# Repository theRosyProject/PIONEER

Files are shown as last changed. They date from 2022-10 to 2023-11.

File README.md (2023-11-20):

# PIONEER
Marie Skłodowska-Curie grant agreement No. 844526 

https://cordis.europa.eu/project/id/844526

## Publications
Dallo, Federico, et al. "Calibration and assessment of electrochemical low-cost sensors in remote alpine harsh environments." Atmospheric Measurement Techniques 14.9 (2021): 6005-6021. https://doi.org/10.5194/amt-14-6005-2021

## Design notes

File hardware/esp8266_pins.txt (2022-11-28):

# Connections with the LoRa Module
3V -- 3V
GND -- GND
14/SCK -- SCK
13/MOSI -- MOSI
12/MISO -- MISO
15 -- G0
16 -- RST
2 -- CS

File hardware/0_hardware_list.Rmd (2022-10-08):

---
title: "Harware List"
author: 
  - "Federico Dallo"
  - "Naichen Zhao"
date: "2022-09-19"
output: html_document
---

```{r setup, include=FALSE}
knitr::opts_chunk$set(echo = TRUE)
```

# List of modules

## Box 1: Data Communication 

The data communication box will receive data (UART) from `Box 2: Data Collection` and will be powered (9V - 5V) with the `Box 3: Power Supply`.

The PCB have to be design to act both as `receiver` and `transceiver` and capable to plug-in commercial components:

- Raspberry Pi Zero ([3B+](https://www.raspberrypi.com/products/raspberry-pi-3-model-b-plus/), [Zero](https://www.raspberrypi.com/products/raspberry-pi-zero-2-w/)) 
- Arduino [Nano BLE](https://store-usa.arduino.cc/products/arduino-nano-33-ble?selectedStore=us)
- [ESP32-S3-MINI-1](https://www.adafruit.com/product/5477)
   - [documentation](https://docs.espressif.com/projects/arduino-esp32/en/latest/installing.html)
- [Feather Huzzah ESP8266](https://www.adafruit.com/product/2821)

Additional modules that should be integrated in the PCB:

- [LoRa 868MHz](https://www.adafruit.com/product/3072)
  - [alternative](https://www.digikey.com/en/products/detail/seeed-technology-co.,-ltd/109990166/7033232?utm_adgroup=RF%20Transceiver%20Modules&utm_source=google&utm_medium=cpc&utm_campaign=Shopping_Product_RF%2FIF%20and%20RFID_NEW&utm_term=&utm_content=RF%20Transceiver%20Modules&gclid=CjwKCAjwpqCZBhAbEiwAa7pXeRL7nhQhQ7vTGvsG-45Smy6gd5Uc4cDUkz6kC4OnWObWKTFqP0Ql0xoCmRAQAvD_BwE)
- Temperature/Humidity/Pressure [BME280](https://www.adafruit.com/product/2652)
- [RTC](https://www.adafruit.com/product/3013)

The connectors that should be on the board:

- Power (USB-C) *Note: the connection should be protected inside the box, with a kind of internal "winding" of the wire to prevent detachment from the board
- [SMA (example)](https://www.adafruit.com/product/1865) 
- [3-pins power connector](https://www.amazon.com/CNLINKO-Industrial-Connector-Receptacles-Waterproof/dp/B06XFM835T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)
- [4-pins data communication connector](https://www.amazon.com/CNLINKO-Industrial-Connector-Receptacles-Waterproof/dp/B06XFMQHWM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)

Notes:

- 868 MHz antenna
  - (Taoglass)[https://www.taoglas.com/product/barracuda-omb-868-05f21-868mhz-omni-directional-outdoor-antenna/]

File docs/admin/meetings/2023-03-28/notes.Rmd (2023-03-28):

---
title: "2023-03-28"
author: "Federico Dallo"
date: "`r Sys.Date()`"
output: html_document
---

```{r setup, include=FALSE}
knitr::opts_chunk$set(echo = TRUE)
```

## Note

- (High) How much time for assembling sensing systems and gateways? 
  - Cost per unit? Prepare: 20 PAT, 100 RICK
- (Medium) Design CAD of the RICK sensors' holes

## PCB updates

- (Low) Add a LoRa 868 MHz antenna on the PAT PCB, on the corner (https://www.proto-electronics.com/blog/how-to-design-pcb-antennas)
- (Medium) Add RTC to the RICK PCB (below?, on the same i2c connections used for the x49 ADC? Loosing CO2, which is ok as CO2 is more important in homes where there is wifi and there is no need of RTC and SD CARD)
- (High - Documentation) Add minimum instruction/labels on the sensors' PCB to ease the installation of modules.
  - ADC mounting orientation and i2c address (RTC orientation as well for the x49 ADC)
  - 4 pin for the CO2 sensor should have V-G-N-P labels
  - 4 pin TX-RX-GND-V on the power and serial
  
## Next Project: Indoor Environment

- EPS8266 controller
- junction box (https://www.thespruce.com/electrical-switch-and-junction-boxes-1824666)
- cover plate: holes for the sensors, button for configuration & reset, led for debug. (If possible an USB Type A for interfacing with the esp, but also for recharging a phone?)
- if not possible having an USB Type A socket, provide a USB socket easy to access when removing the plate, for eventual direct access to the microcontroller

## Other

- (Low) Add an IP56 USB socket on the box

## Aknowledgement

PIONEER ... module
F. Dallo & N. Zhao

## Citation

### Place the original in Spanish
Defender la alegría como una trinchera,
un principio, una bandera, un destino,
una certeza, un derecho. (M. Benedetti)

Difendere l’allegria come una trincea, 
un principio, una bandiera, un destino, 
una certezza, un diritto. (M. Benedetti)

http://tiltingourheadsup.blogspot.com/2012/11/mario-benedetti-in-defence-of-joy.html

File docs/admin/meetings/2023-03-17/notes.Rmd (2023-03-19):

---
title: "Notes"
author: "Federico Dallo"
date: "`r Sys.Date()`"
output: html_document
---

```{r setup, include=FALSE}
knitr::opts_chunk$set(echo = TRUE)
```

## Updates to be made on Sensor PCB

Add minimum instruction/labels on the sensors' PCB to ease the installation of modules.
For example: 

- ADC mounting orientation and i2c address
- 4 pin for the CO2 sensor should have V-G-N-P labels
- 4 pin TX-RX-GND-V on the power and serial

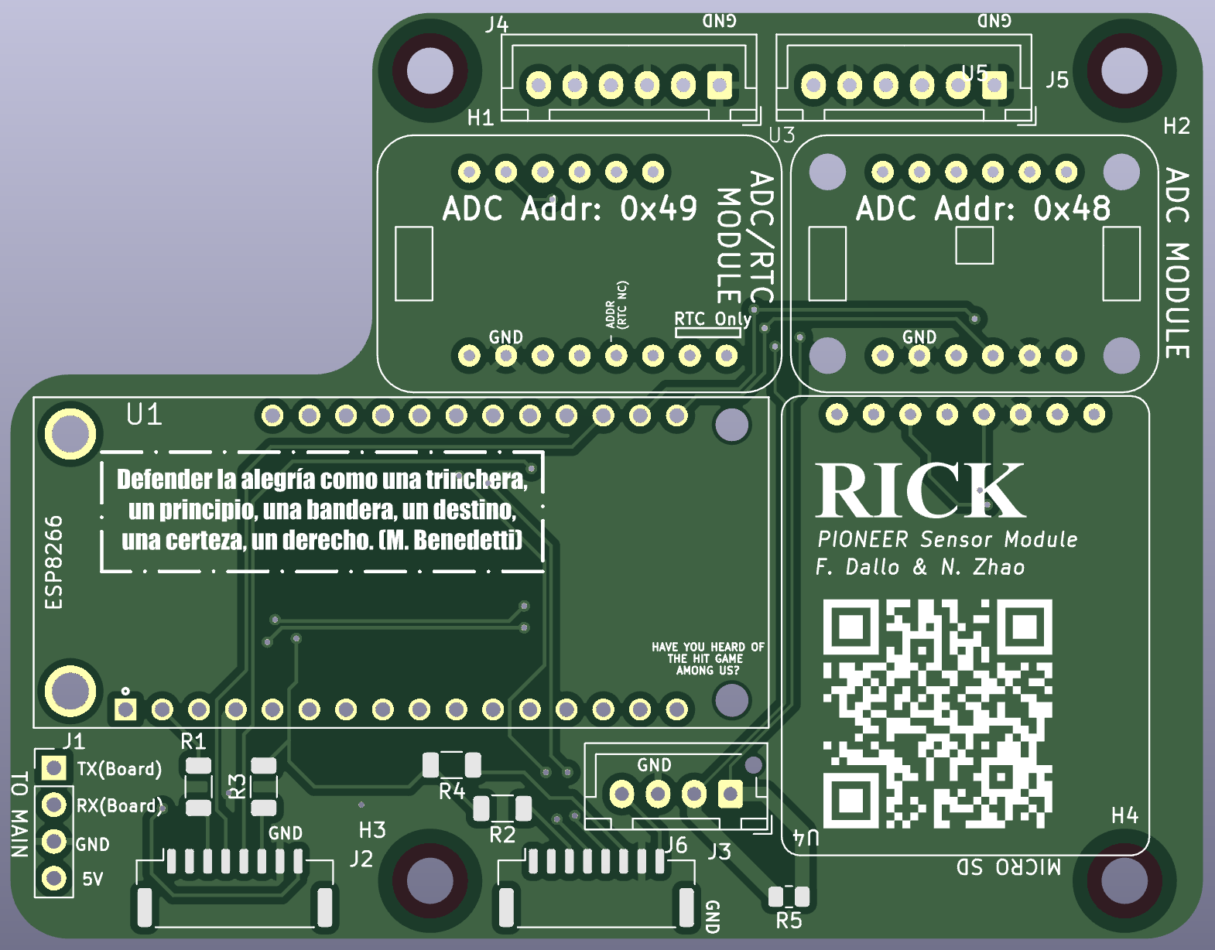
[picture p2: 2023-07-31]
hardware/RICK_v1.png

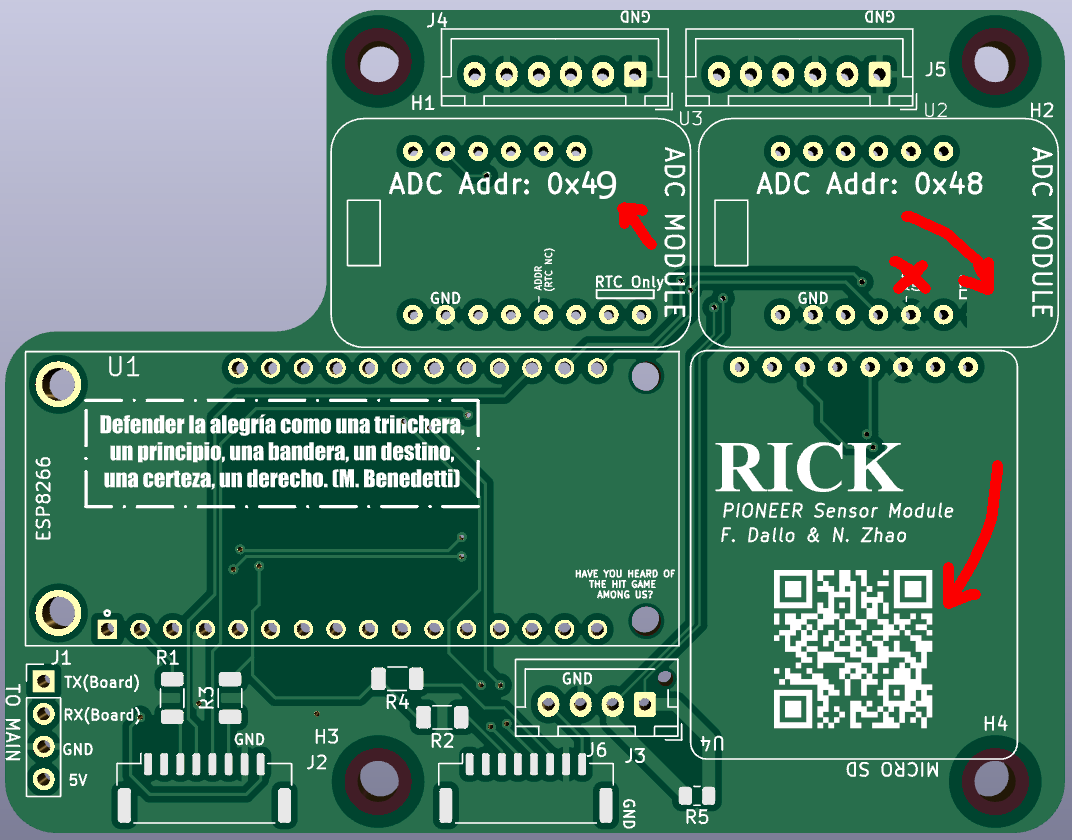
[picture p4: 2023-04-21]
docs/admin/meetings/2023-04-20/RICK.png

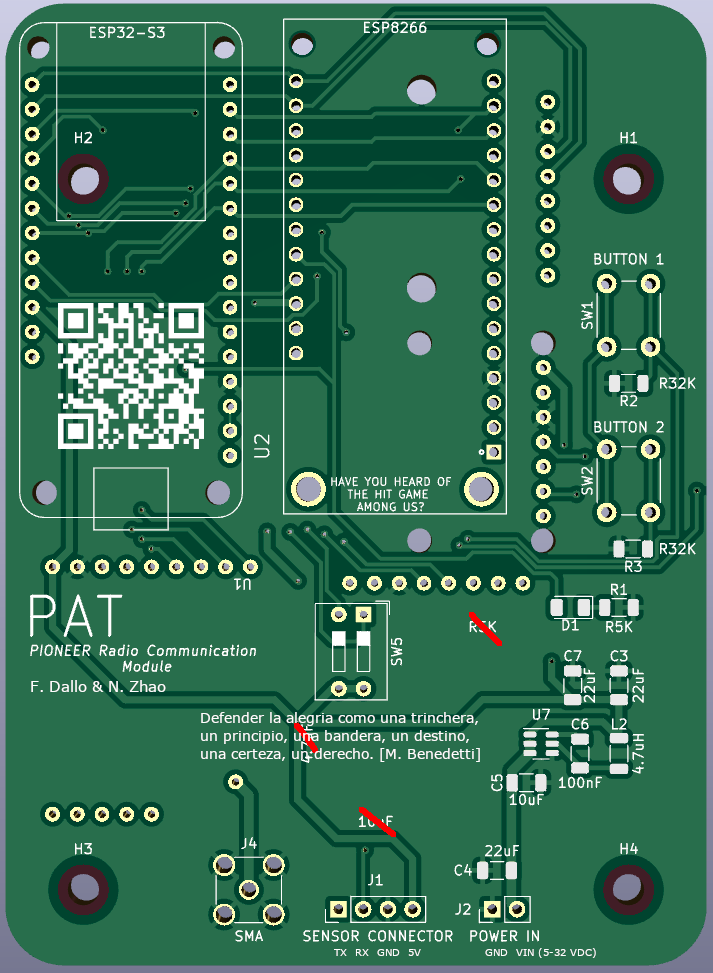
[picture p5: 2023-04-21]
docs/admin/meetings/2023-04-20/PAT.png

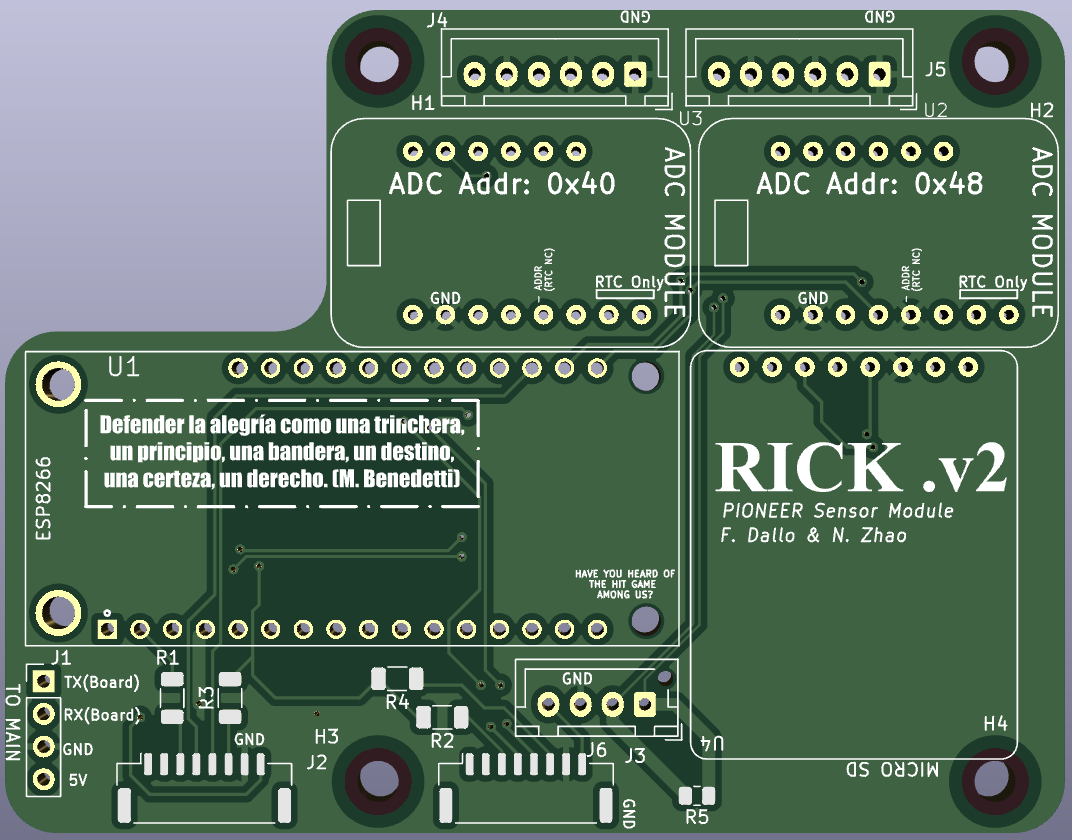
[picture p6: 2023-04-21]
docs/admin/meetings/2023-04-20/Screenshot 2023-04-20 at 15.49.45.png

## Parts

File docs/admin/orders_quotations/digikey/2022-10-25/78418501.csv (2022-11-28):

# | QUANTITY | PART NUMBER | MANUFACTURER PART NUMBER | DESCRIPTION | CUSTOMER REFERENCE | BACKORDER | UNIT PRICE | EXTENDED PRICE
1 | 50 | 399-C1206C472K5RACAUTOCT-ND | C1206C472K5RACAUTO | CAP CER 4700PF 50V X7R 1206 |  | 0 | 0.07500 | 3.75
2 | 20 | 399-17654-1-ND | C1206C103JBGAC7800 | CAP CER SMD 1206 .01UF 630V 5% C |  | 0 | 0.72400 | 14.48
3 | 50 | 445-5840-1-ND | CGA5L2X7R2A104K160AA | CAP CER 0.1UF 100V X7R 1206 |  | 0 | 0.13340 | 6.67
4 | 20 | 478-12850-1-ND | 1206CC223KAT1A | CAP CER 0.022UF 630V X7R 1206 |  | 0 | 0.53000 | 10.60
5 | 20 | 160-1737-1-ND | LTW-150TK | LED WHITE CHIP SMD |  | 0 | 0.36900 | 7.38
6 | 25 | 283-MCQ1V3216-2R2-RCT-ND | MCQ1V3216-2R2-R | FIXED IND 2.2UH 50MA 500MOHM SMD |  | 0 | 0.06480 | 1.62
7 | 20 | 4161-CTML1206F-4R7K-ND | CTML1206F-4R7K | 4.7UH FER MULTIL SHLD INDUCTOR |  | 0 | 0.22000 | 4.40
8 | 25 | 2223-DS01-254-L-02BE-ND | DS01-254-L-02BE | DIP SWITCH, SPST, 2.54 PITCH, RA |  | 0 | 0.46480 | 11.62
9 | 10 | LM3671MF-3.3/NOPBCT-ND | LM3671MF-3.3/NOPB | IC REG BUCK 3.3V 600MA SOT23-5 |  | 0 | 1.56500 | 15.65
10 | 10 | AP63205WU-7DICT-ND | AP63205WU-7 | IC REG BUCK 5V 2A TSOT26 |  | 0 | 0.79900 | 7.99

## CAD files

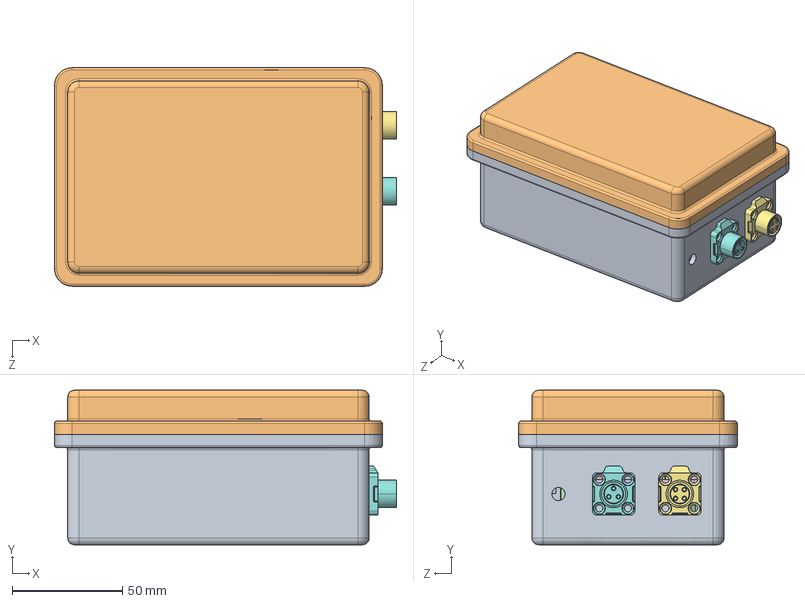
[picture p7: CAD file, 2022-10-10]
hardware/CAD/Box_Assembly.SLDASM
154.9 x 70.0 x 99.0 mm
PCB_Holder
15mm Standoff x 4
CONSMA001-ND
Tactal Switch -Thru (6mmx 6mmx4.5mm) x 4
SW-NDS-02V.stp
12er Pin Header Female.step x 2
16er Pin Header Female.step x 2
8er Pin Header Female.step
7er Pin Header Female.step
5er Pin Header Female.step
9er Pin Header Female.step
Pioneer Controller
Connector Cnlinko LP-12 4 poles
Connector Cnlinko LP-12 3 poles

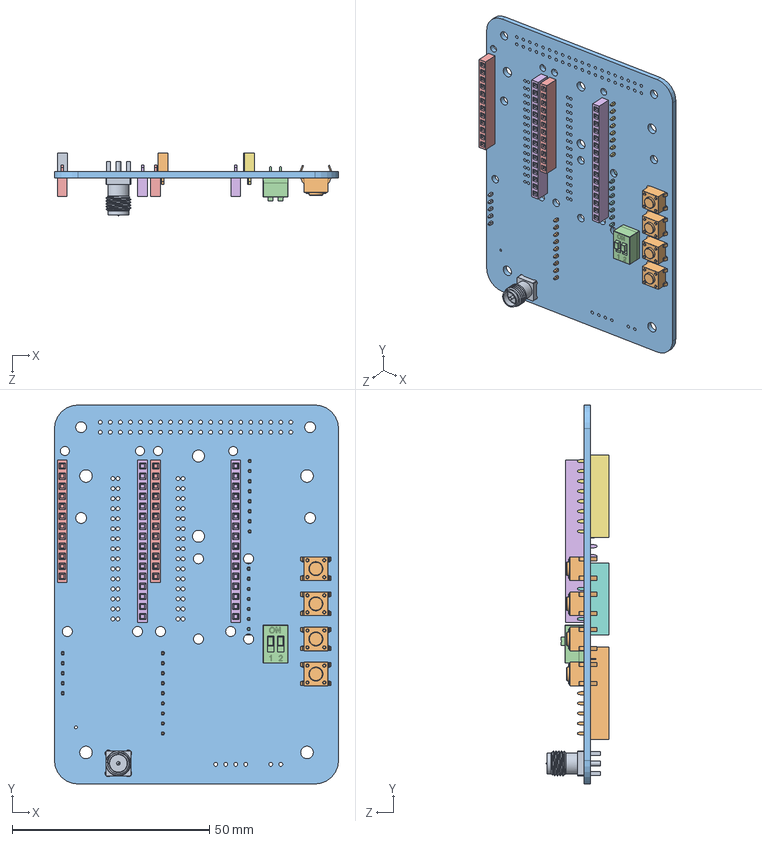
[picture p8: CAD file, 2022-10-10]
hardware/CAD/PCB Models/PCB_Assembly.SLDASM
72.0 x 96.0 x 16.0 mm
CONSMA001-ND
Tactal Switch -Thru (6mmx 6mmx4.5mm) x 4
PCB_Board
SW-NDS-02V.stp
12er Pin Header Female.step x 2
16er Pin Header Female.step x 2
8er Pin Header Female.step
7er Pin Header Female.step
5er Pin Header Female.step
9er Pin Header Female.step

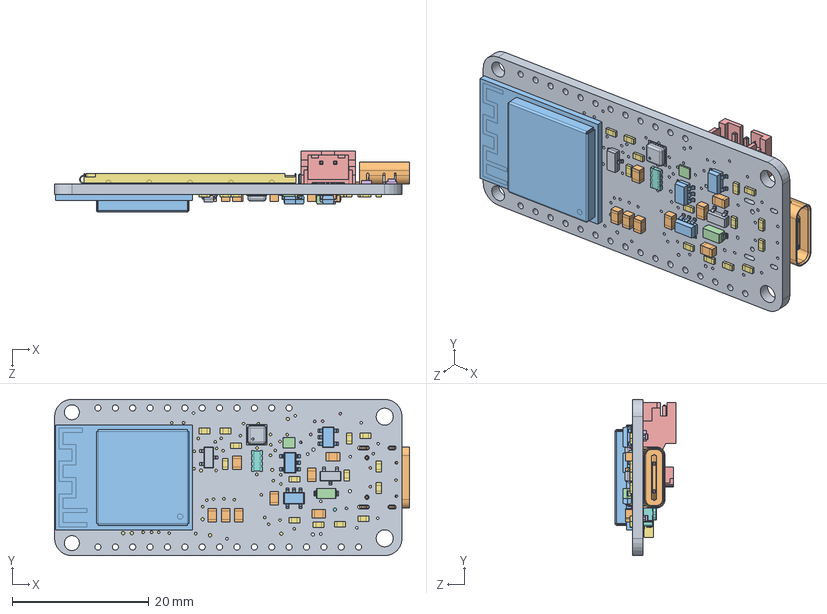
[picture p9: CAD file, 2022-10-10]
hardware/Controller Box/PCB Models/Controllers/ESP32-S2/5300 ESP32-S2 TFT Feather.SLDASM
51.9 x 22.9 x 8.92 mm
Board.step
10uF.step x 8
AP2112-3.3.step x 3
MBR540.step
JSTPH.step
RED.step x 2
1uF.step x 14
KMR2.step x 2
BSS138.step x 2
USB C.step
ESP32-S2-MODULE_MINI.step
LC709203F_MH.step
STEMMA_I2C_QTRA.step
WS2812B_SK6805_1515.step
DISP_LCD_GENERIC_SPI_1.14IN_240X135_WRAPUNDER.step
10K.step
BME680.step

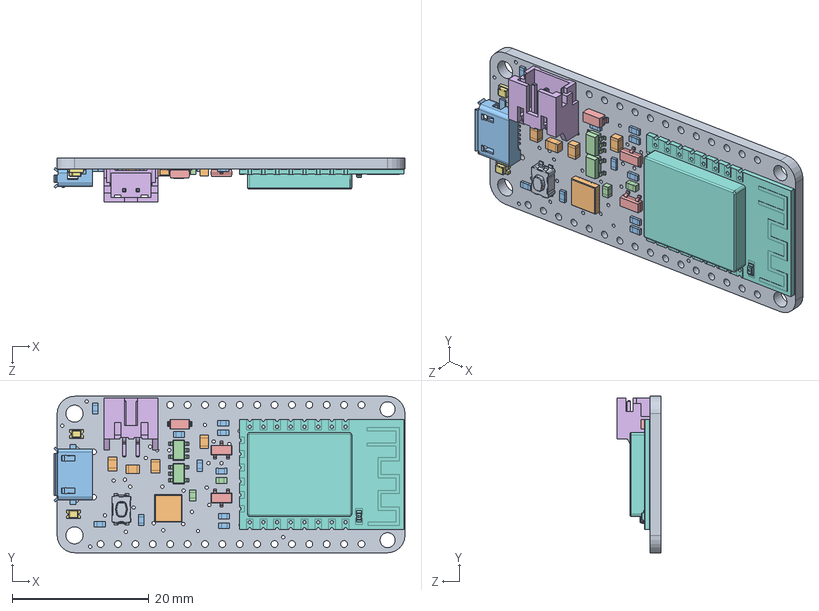
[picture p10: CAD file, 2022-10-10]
hardware/Controller Box/PCB Models/Controllers/ESP8266/Adafruit ESP8266 Feather.SLDASM
51.3 x 22.9 x 6.37 mm
Board.step
10uF.step x 4
10K.step x 10
MCP73831T-2ACI_OT.step x 2
MBR120.step
JSTPH.step
RED.step x 2
ESP-12.step
KMR2.step
CP2104.step
20329.step
1K.step x 2
mmbt2222.step x 2

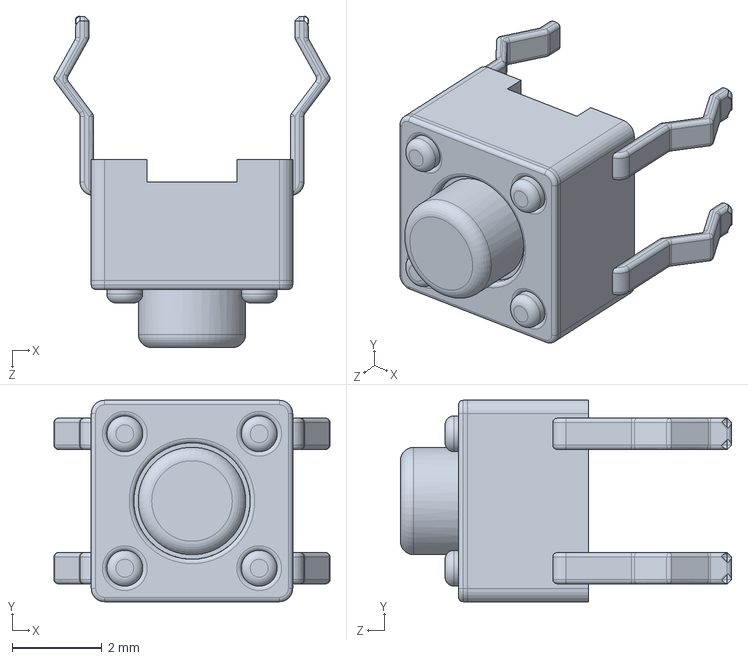
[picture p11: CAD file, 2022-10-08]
hardware/Controller Box/PCB Models/Tact Switch 4.5mm.SLDASM
6.16 x 4.50 x 7.40 mm

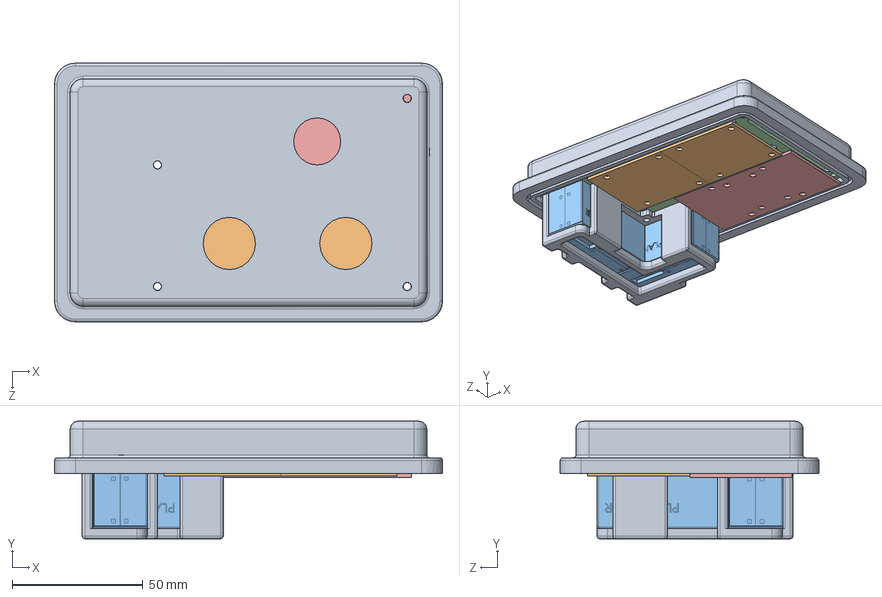
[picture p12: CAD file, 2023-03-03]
hardware/Sensor Box/Sensor_Box_Top_Ass.SLDASM
148.5 x 45.0 x 99.0 mm
Sensor_Box_Lid
Alphsense_Gas_Sensor x 2
PMS5003 x 2
top_frame
NDIR Transmitter
10mm Standoff x 4
3mm Standoff x 4
2.5mm Standoff x 8
PM5_frame

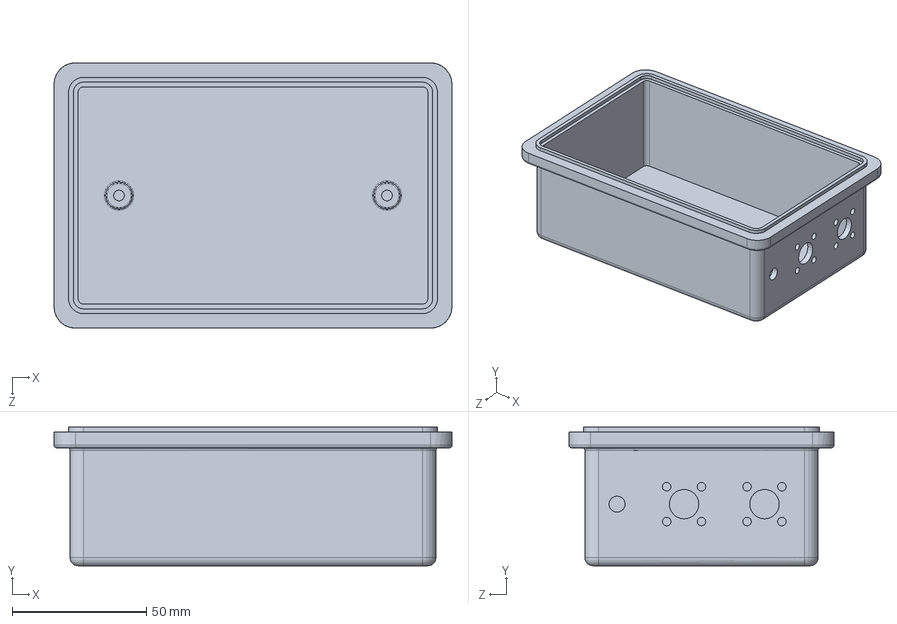
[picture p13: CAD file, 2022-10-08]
hardware/Controller Box/Box/Box_Bottom.SLDPRT
148.5 x 51.7 x 99.0 mm

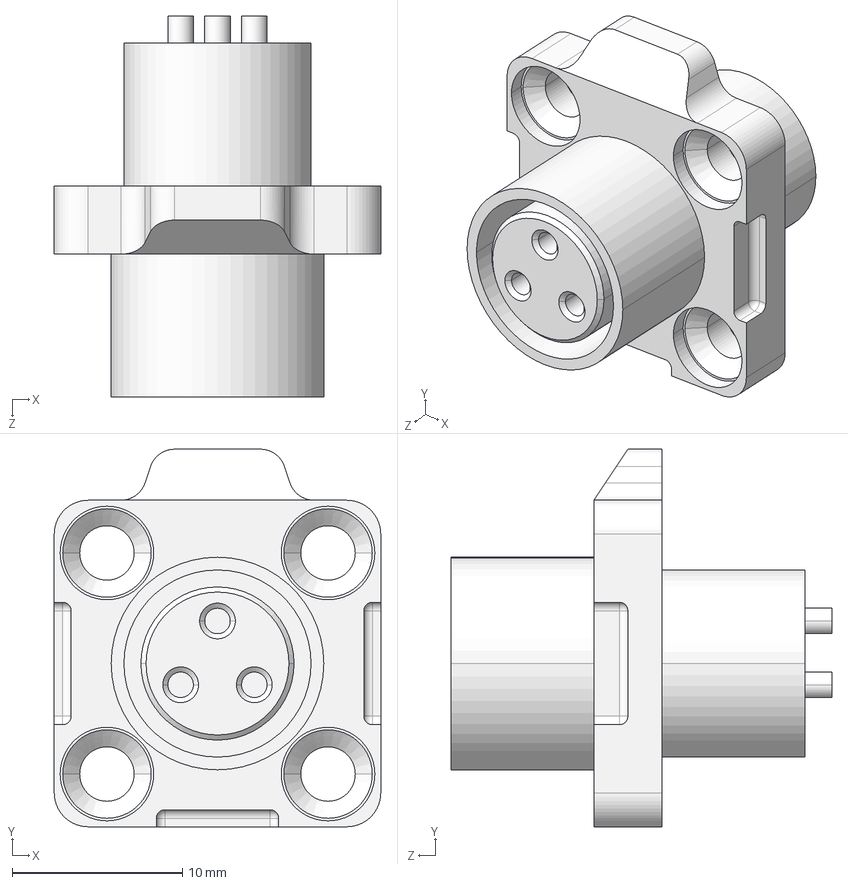
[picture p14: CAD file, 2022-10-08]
hardware/Controller Box/Connectors/Connector Cnlinko LP-12 3 poles.STEP
19.2 x 22.2 x 22.4 mm

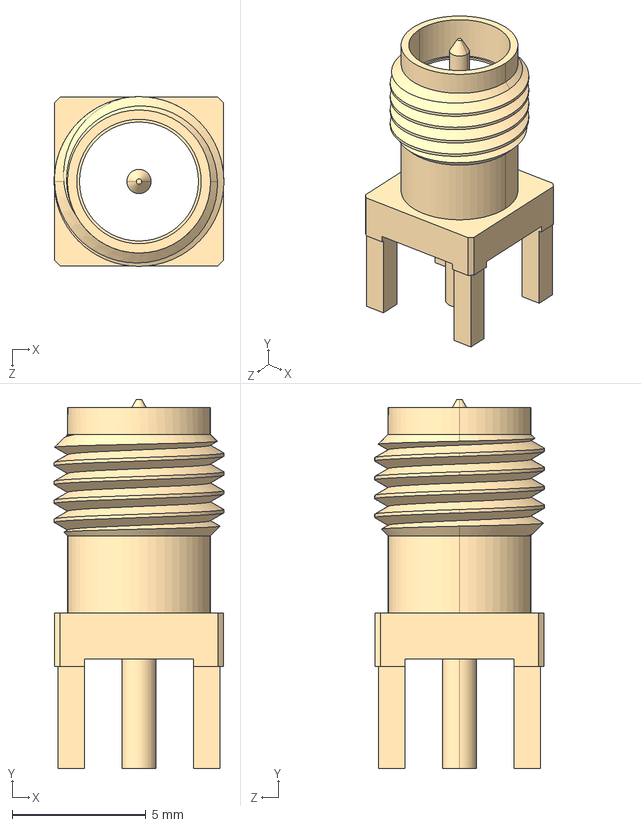
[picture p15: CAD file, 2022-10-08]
hardware/Controller Box/PCB Models/CONSMA001-ND/CONSMA001-ND.STEP
6.35 x 13.8 x 6.35 mm

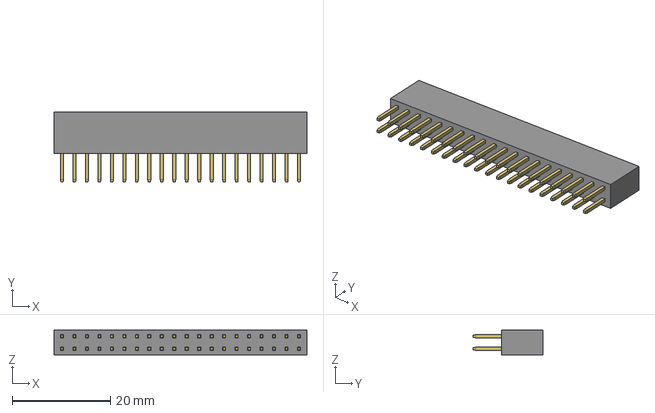
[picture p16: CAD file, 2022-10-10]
hardware/Controller Box/PCB Models/female_header_pins/2x20 Stacking Header.step
51.5 x 14.3 x 5.08 mm

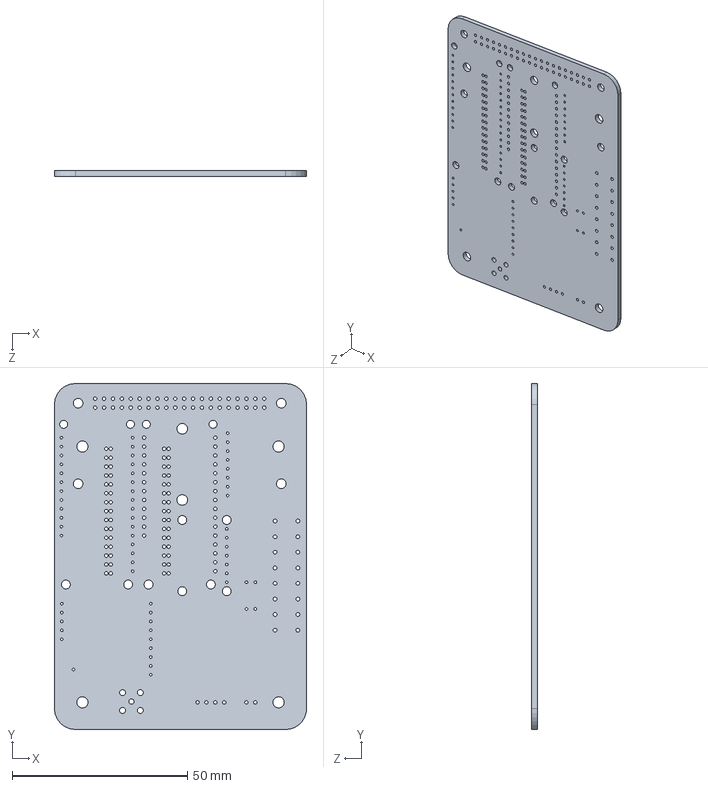
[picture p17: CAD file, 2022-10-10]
hardware/Controller Box/PCB Models/Pioneer Controller.SLDPRT
72.0 x 98.8 x 1.60 mm

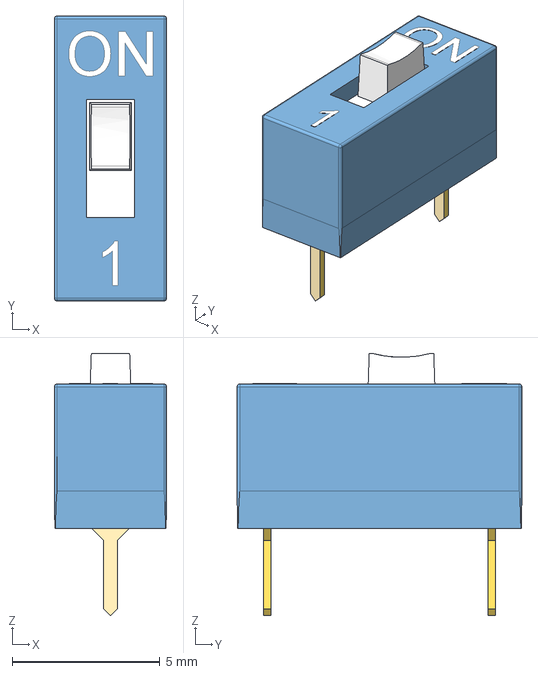
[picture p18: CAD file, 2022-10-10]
hardware/Controller Box/PCB Models/stp/SW-NDS-01V.stp
3.81 x 9.65 x 8.88 mm

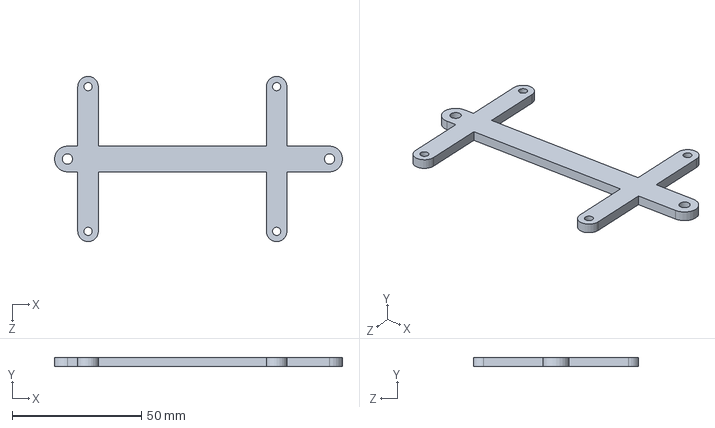
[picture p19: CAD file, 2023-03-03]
hardware/Controller Box/PCB_Holder.SLDPRT
111.5 x 3.50 x 64.0 mm

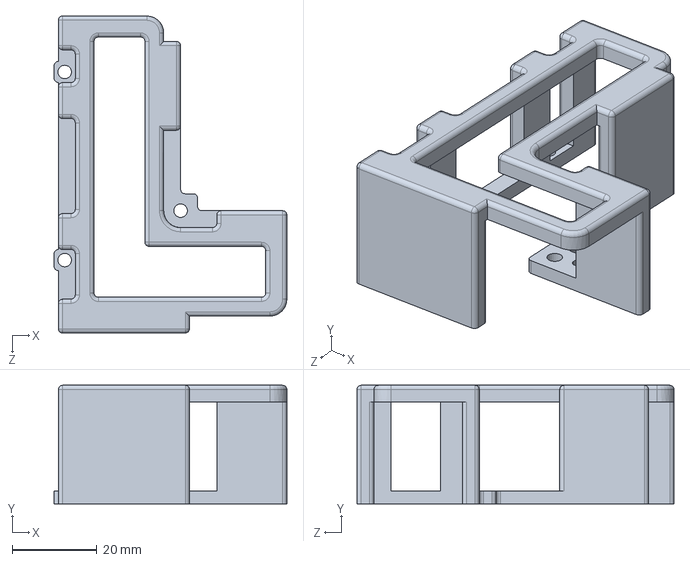
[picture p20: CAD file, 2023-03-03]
hardware/Sensor Box/PM5_frame.SLDPRT
55.0 x 28.0 x 74.9 mm

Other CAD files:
hardware/Controller Box/PCB Models/Board.SLDASM
hardware/Sensor Box/Sensor Box/Sensor_Box_Bottom.SLDPRT
hardware/Sensor Box/Sensors/NDIR Transmitter.SLDPRT
hardware/Controller Box/Box/Box_Lid.SLDPRT
hardware/Controller Box/Connectors/Connector Cnlinko LP-12 2 poles.SLDPRT
hardware/Controller Box/Connectors/Connector Cnlinko LP-12 2 poles.STEP
hardware/Controller Box/Connectors/Connector Cnlinko LP-12 3 poles.SLDPRT
hardware/Controller Box/Connectors/Connector Cnlinko LP-12 4 poles.SLDPRT
hardware/Controller Box/Connectors/Connector Cnlinko LP-12 4 poles.STEP
hardware/Controller Box/PCB Models/Board.SLDPRT
hardware/Controller Box/PCB Models/CONSMA001-ND/CONSMA001-ND.SLDPRT
hardware/Controller Box/PCB Models/Controllers/ESP8266/Adafruit ESP8266 Feather.SLDPRT
hardware/Controller Box/PCB Models/PCB_Board.SLDPRT
hardware/Controller Box/PCB Models/Tact Switch 4.5mm.SLDPRT
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

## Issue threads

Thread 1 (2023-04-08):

Change CS pin for the SD card module

theRosyProject, 2023-04-08:
In the RICK PCB the SD card module has CS pin connected to ESP8266-feather-huzzah pin 14. Unfortunately this is not working, this pin seems to a shared CLK pin.. very annoying. We should change it to pin 16. Working after testing on a protoboard.

naichenzhao, 2023-04-11:
done

Closed 2023-04-11.

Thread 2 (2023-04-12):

BOM: update component list and infos

theRosyProject, 2023-04-12:
1) Sheet "Controller Box V2", line 11 (see orange underline):
- there is a broken link for the Inductor 4.7uH SMD - 1206
- provide a precise or estimated unit cost (column I)

2) Both "Controller Box V2" and "Sensor Box":
- check that the values in column H are correct, in red the differences between column H and D.
- provide an estimated production cost per units and shipping cost (Controller Box V2: line 35-36, Sensor Box: line 16-17)

theRosyProject, 2023-04-20:
BOM updated.

Closed 2023-04-20.

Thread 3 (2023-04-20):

RICK: i2c address of ADC module

theRosyProject, 2023-04-20:
The 2nd ADC should have label indicating Addr: 0x49 (not 40)

theRosyProject, 2023-04-20:
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

theRosyProject, 2023-04-24:
solved

Closed 2023-04-24.

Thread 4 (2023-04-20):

RICK: RTC module on ADC 0x49

theRosyProject, 2023-04-20:
The RTC can be used instead of the ADC 0x49, NOT in place of the ADC 0x48, as for the latter case the BAT (5V) pin of the RTC would be connected to GND!

Fix: remove the 2 pins and labels for the RTC module.

theRosyProject, 2023-04-20:
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

theRosyProject, 2023-04-24:
solved

Closed 2023-04-24.

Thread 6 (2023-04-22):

Laser-cut enclosure

theRosyProject, 2023-04-22:
Currently enclosure box is a commercial junction box (e.g., Zulkit Junction Box ABS Plastic Dustproof Waterproof IP65 Electrical Boxes Hinged Shell Outdoor Universal Project Enclosure with 2 Cable Glands 5.9 x 3.9 x 2.8 inch (150x100x70mm)).

Start to work on a dedicated enclosure for indoor space.

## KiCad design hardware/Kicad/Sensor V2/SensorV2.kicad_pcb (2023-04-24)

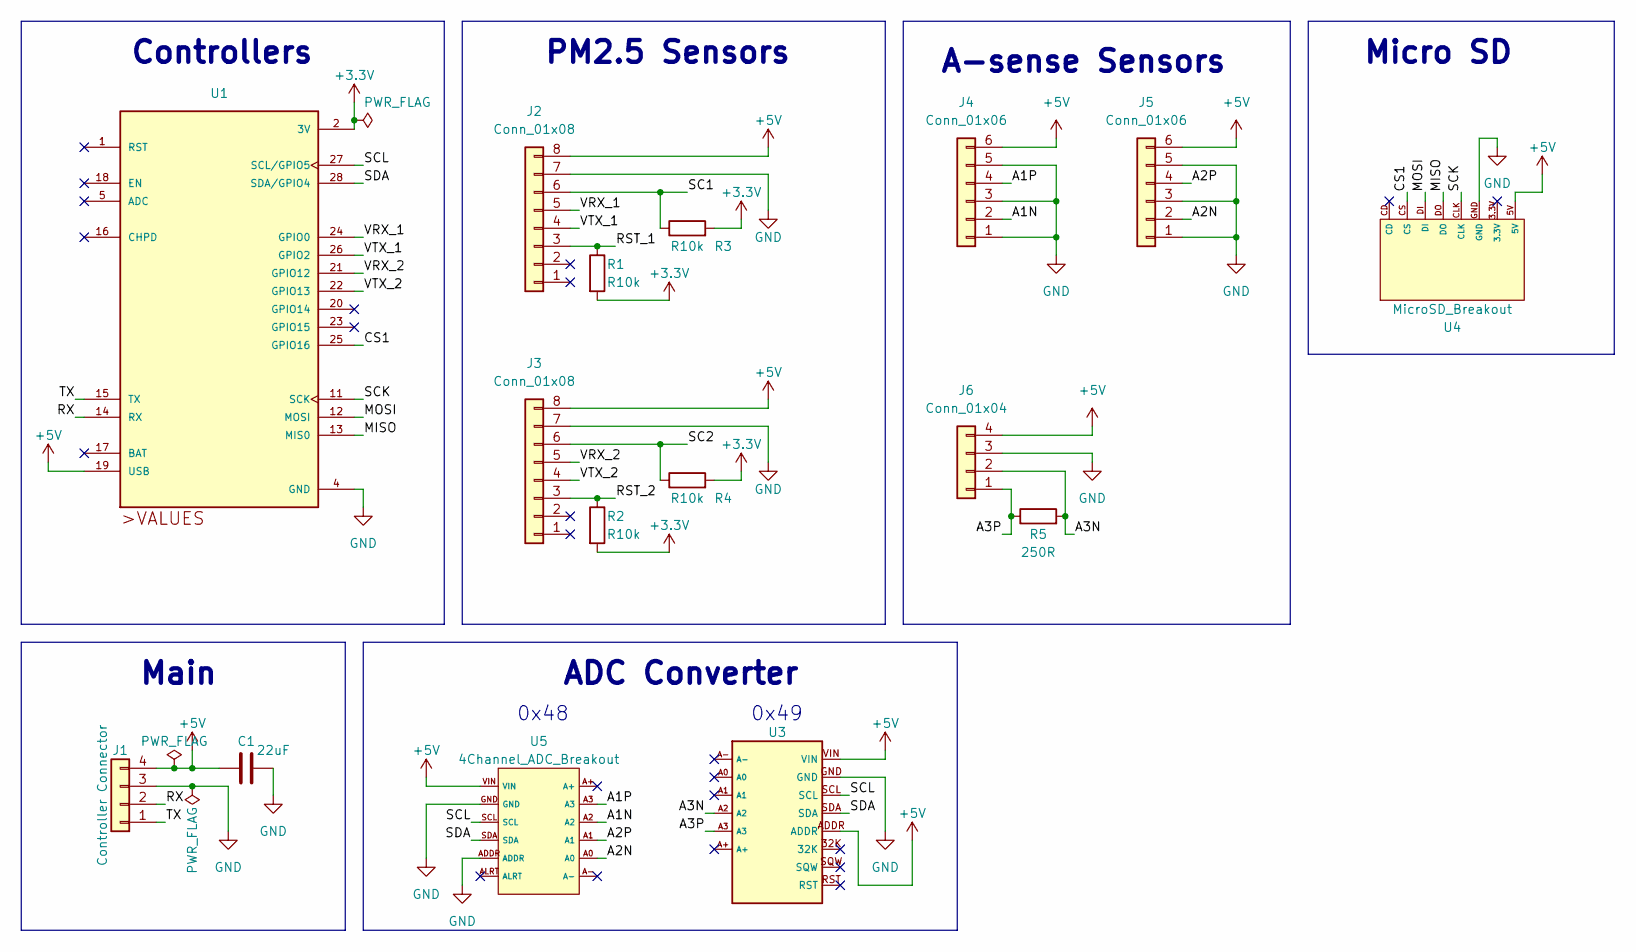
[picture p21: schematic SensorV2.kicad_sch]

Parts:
C1: 22uF; C_1206_3216Metric
J1: Controller Connector; PinHeader_1x04_P2.54mm_Vertical
J2, J3: Conn_01x08; Molex_CLIK-Mate_502386-0870_1x08-1MP_P1.25mm_Horizontal
J4, J5: Conn_01x06; JST_XH_B6B-XH-A_1x06_P2.50mm_Vertical
J6: Conn_01x04; JST_XH_B4B-XH-AM_1x04_P2.50mm_Vertical
R1, R2, R3, R4: R10k; R_1206_3216Metric
R5: 250R; R_0805_2012Metric
U1: 2821; XCVR_Adafruit Feather ESP8266
U3: ADCRTC_Dual
U4: MicroSD_Breakout
U5: 4Channel_ADC_Breakout; 4Channel ADC Breakout

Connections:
+3V3: R1.2, R2.2, R3.2, R4.2, U1.2 (3V)
+5V: C1.1, J1.4, J2.8, J3.8, J4.6, J5.6, J6.4, U1.19 (USB), U3.ADDR, U3.VIN, U4.5V, U5.VIN
/A1N: J4.2, U5.A2
/A1P: J4.4, U5.A3
/A2N: J5.2, U5.A0
/A2P: J5.4, U5.A1
/A3N: J6.2, R5.2, U3.A2
/A3P: J6.1, R5.1, U3.A3
/CS1: U1.25 (GPIO16), U4.CS
/MISO: U1.13 (MIS0), U4.DO
/MOSI: U1.12 (MOSI), U4.DI
/RST_1: J2.3, R1.1
/RST_2: J3.3, R2.1
/RX: J1.2, U1.14 (RX)
/SC1: J2.6, R3.1
/SC2: J3.6, R4.1
/SCK: U1.11 (SCK), U4.CLK
/SCL: U1.27 (SCL/GPIO5), U3.SCL, U5.SCL
/SDA: U1.28 (SDA/GPIO4), U3.SDA, U5.SDA
/TX: J1.1, U1.15 (TX)
/VRX_1: J2.5, U1.24 (GPIO0)
/VRX_2: J3.5, U1.21 (GPIO12)
/VTX_1: J2.4, U1.26 (GPIO2)
/VTX_2: J3.4, U1.22 (GPIO13)
GND: C1.2, J1.3, J2.7, J3.7, J4.1, J4.3, J4.5, J5.1, J5.3, J5.5, J6.3, U1.4 (GND), U3.GND, U4.GND, U5.ADDR, U5.GND

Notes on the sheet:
Controllers
ADC Converter
0x49
A-sense Sensors
Micro SD
Main
0x48
PM2.5 Sensors

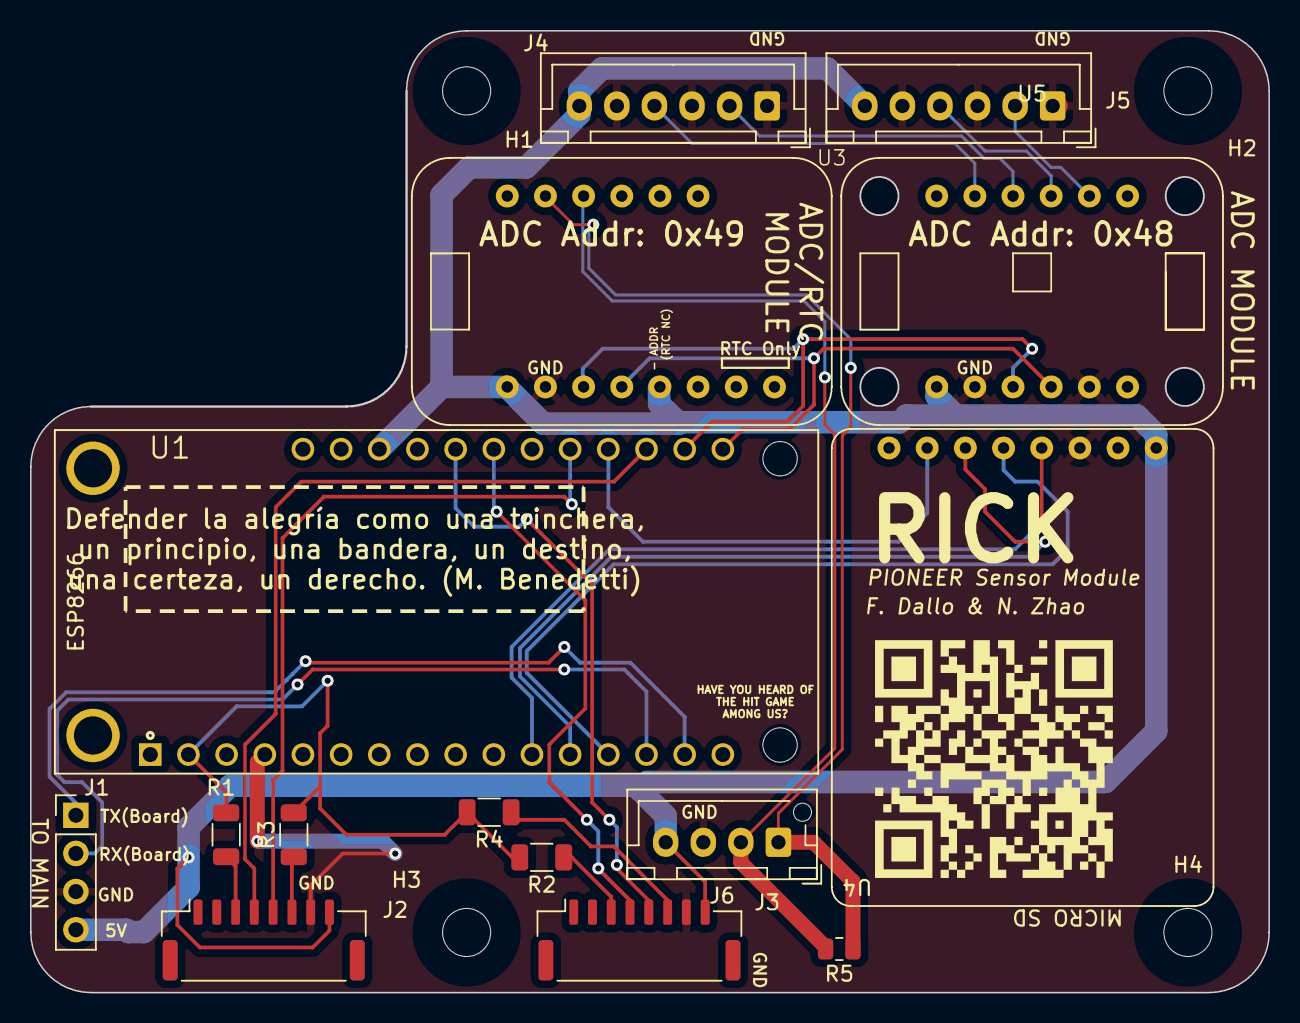
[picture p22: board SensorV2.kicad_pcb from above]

Board: 2 copper layers, 82.4 x 64.0 mm, 20 parts (1 on the bottom side), 25 nets.

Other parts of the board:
H1, H2, H3, H4: MountingHole_3.2mm_M3

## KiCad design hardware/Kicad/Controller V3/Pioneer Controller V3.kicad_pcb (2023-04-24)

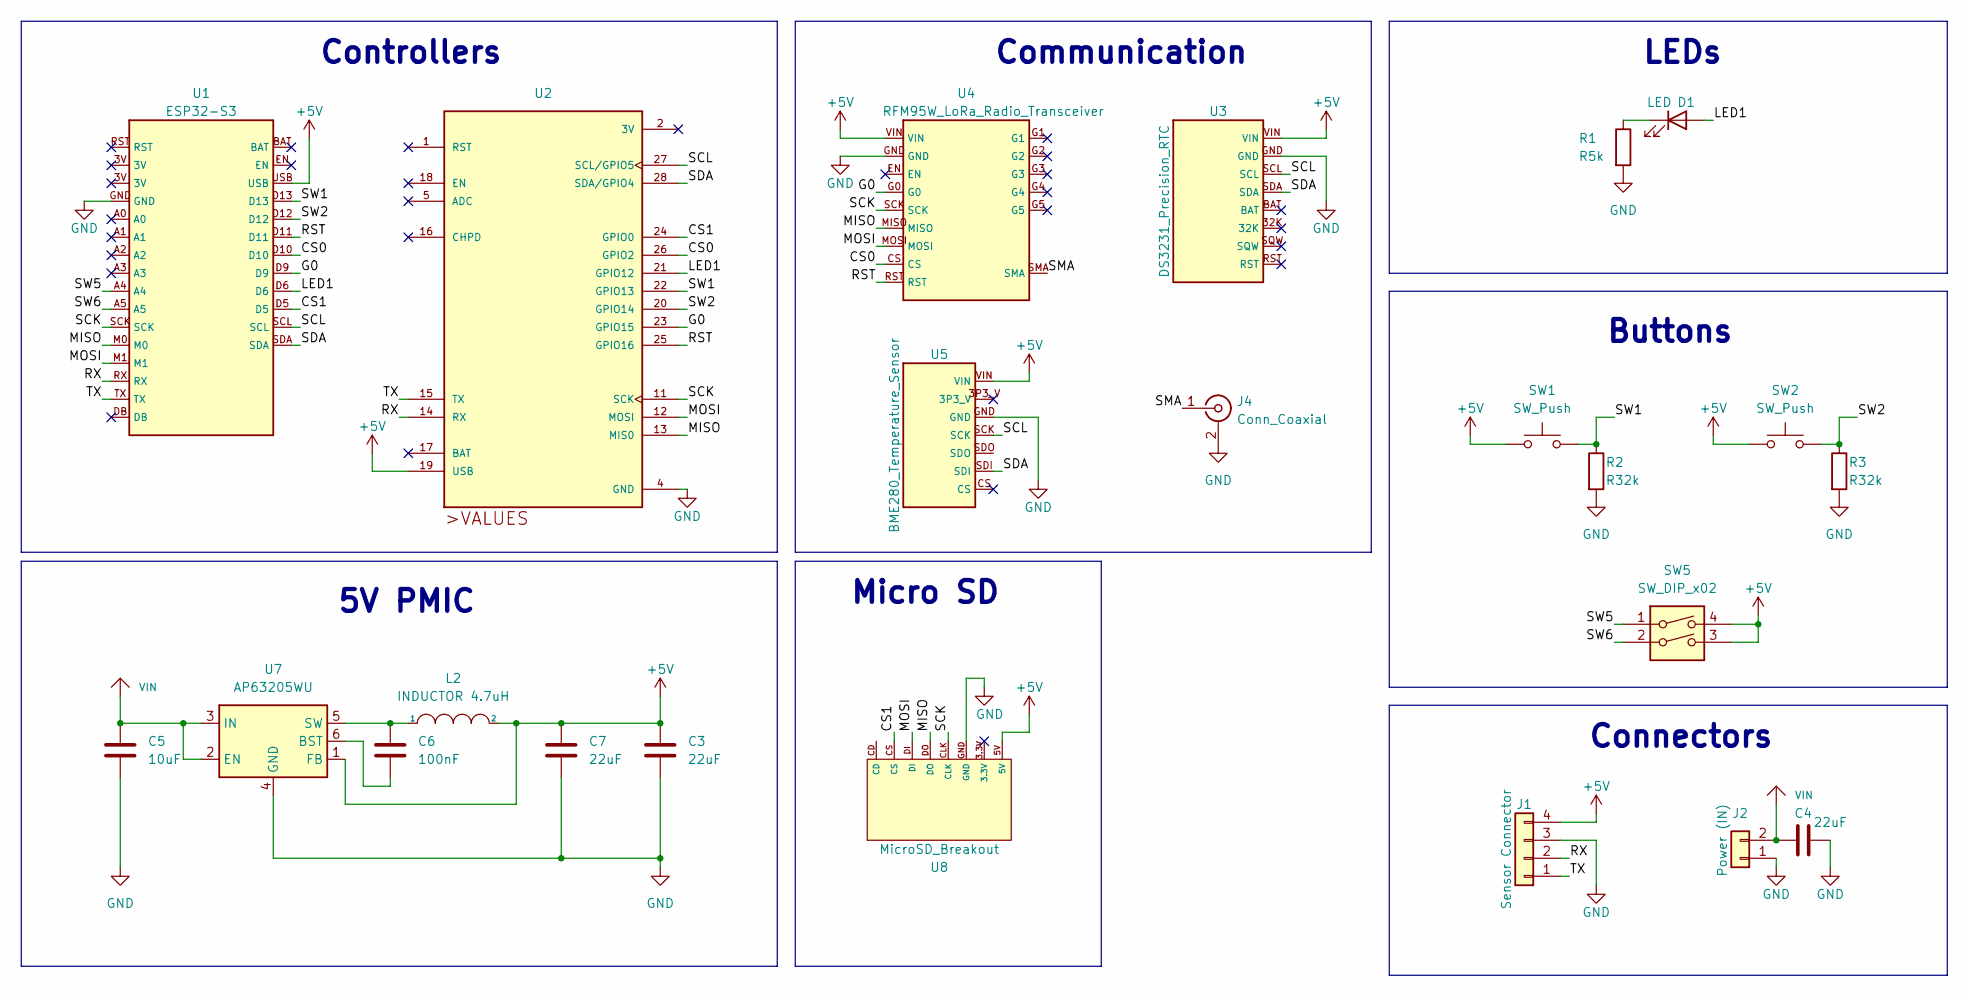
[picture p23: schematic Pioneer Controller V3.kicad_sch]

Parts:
C3, C4, C7: 22uF; C_1206_3216Metric
C5: 10uF; C_1206_3216Metric
C6: 100nF; C_1206_3216Metric
D1: LED; LED_1206_3216Metric
J1: Sensor Connector; PinHeader_1x04_P2.54mm_Vertical
J2: Power (IN); PinHeader_1x02_P2.54mm_Vertical
J4: Conn_Coaxial; SMA_Amphenol_132134-11_Vertical
L2: INDUCTOR 4.7uH; L_1206_3216Metric
R1: R5k; R_1206_3216Metric
R2, R3: R32k; R_1206_3216Metric
SW1, SW2: SW_Push; SW_PUSH_6mm
SW5: SW_DIP_x02; SW_DIP_SPSTx02_Slide_9.78x7.26mm_W7.62mm_P2.54mm
U1: ESP32-S3
U2: 2821; XCVR_Adafruit Feather ESP8266
U3: DS3231_Precision_RTC; DS3231 Precision RTC
U4: RFM95W_LoRa_Radio_Transceiver; FM95W LoRa Radio Transceiver
U5: BME280_Temperature_Sensor; BME280 I2C Temperature Sensor
U7: AP63205WU; TSOT-23-6
U8: MicroSD_Breakout

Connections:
+5V: C3.1, C7.1, J1.4, L2.2, SW1.1, SW2.1, SW5.3, SW5.4, U1.USB, U2.19 (USB), U3.VIN, U4.VIN, U5.VIN, U7.1 (FB), U8.5V
/CS0: U1.D10, U2.26 (GPIO2), U4.CS
/CS1: U1.D5, U2.24 (GPIO0), U8.CS
/G0: U1.D9, U2.23 (GPIO15), U4.G0
/LED1: D1.2 (A), U1.D6, U2.21 (GPIO12)
/MISO: U1.M0, U2.13 (MIS0), U4.MISO, U8.DO
/MOSI: U1.M1, U2.12 (MOSI), U4.MOSI, U8.DI
/RST: U1.D11, U2.25 (GPIO16), U4.RST
/RX: J1.2, U1.RX, U2.14 (RX)
/SCK: U1.SCK, U2.11 (SCK), U4.SCK, U8.CLK
/SCL: U1.SCL, U2.27 (SCL/GPIO5), U3.SCL, U5.SCK
/SDA: U1.SDA, U2.28 (SDA/GPIO4), U3.SDA, U5.SDI
/SMA: J4.1 (In), U4.SMA
/SW1: R2.1, SW1.2, U1.D13, U2.22 (GPIO13)
/SW2: R3.1, SW2.2, U1.D12, U2.20 (GPIO14)
/SW5: SW5.1, U1.A4
/SW6: SW5.2, U1.A5
/TX: J1.1, U1.TX, U2.15 (TX)
GND: C3.2, C4.2, C5.2, C7.2, J1.3, J2.1, J4.2 (Ext), R1.2, R2.2, R3.2, U1.GND, U2.4 (GND), U3.GND, U4.GND, U5.GND, U7.4 (GND), U8.GND
unnamed: D1.1 (K), R1.1
unnamed: C6.2, U7.6 (BST)
unnamed: C6.1, L2.1, U7.5 (SW)
VIN: C4.1, C5.1, J2.2, U7.2 (EN), U7.3 (IN)

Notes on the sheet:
Communication
Controllers
Connectors
Buttons
Micro SD
LEDs
5V PMIC

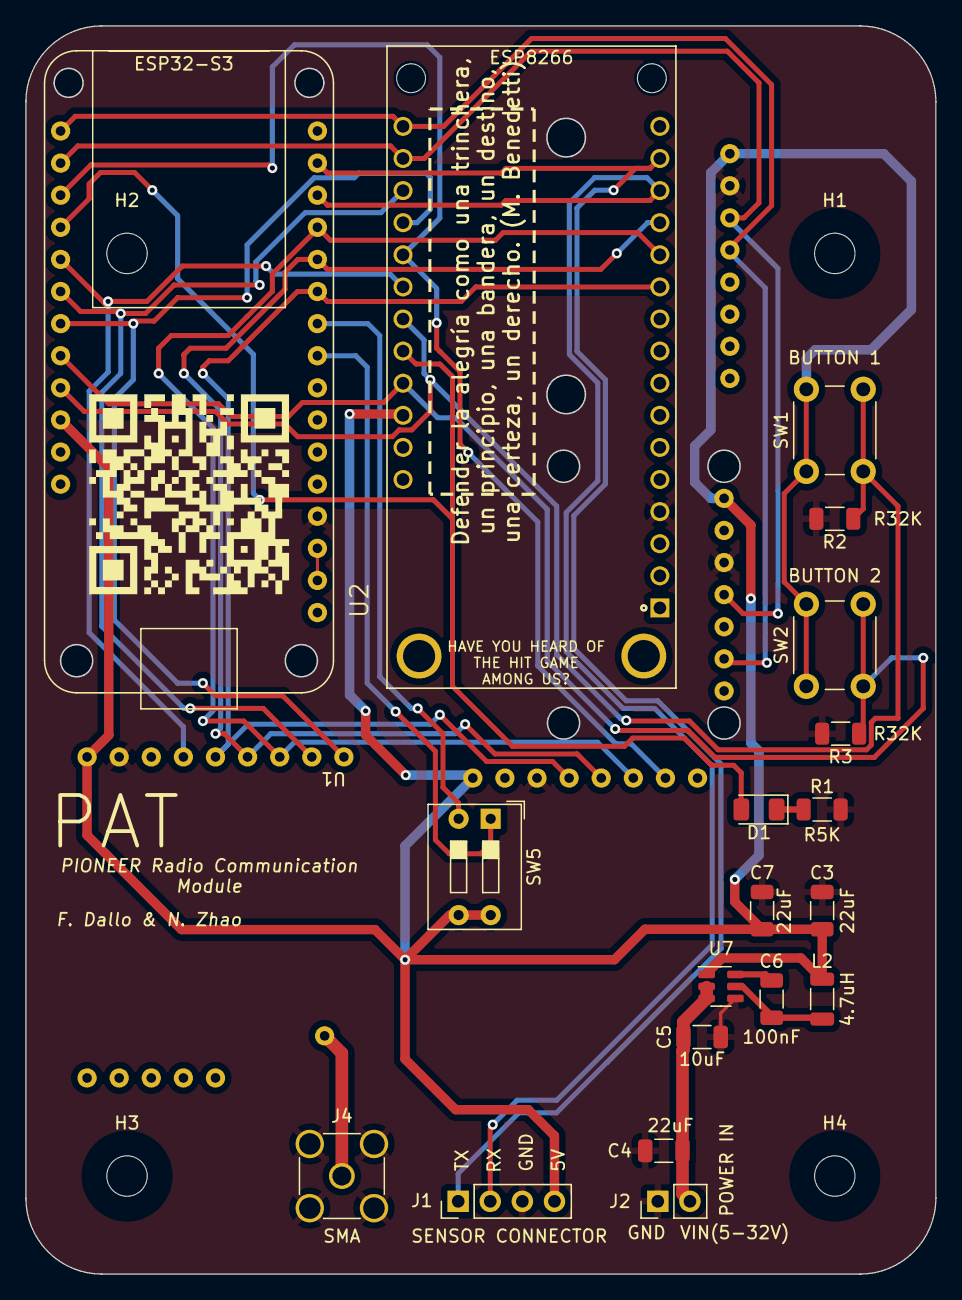
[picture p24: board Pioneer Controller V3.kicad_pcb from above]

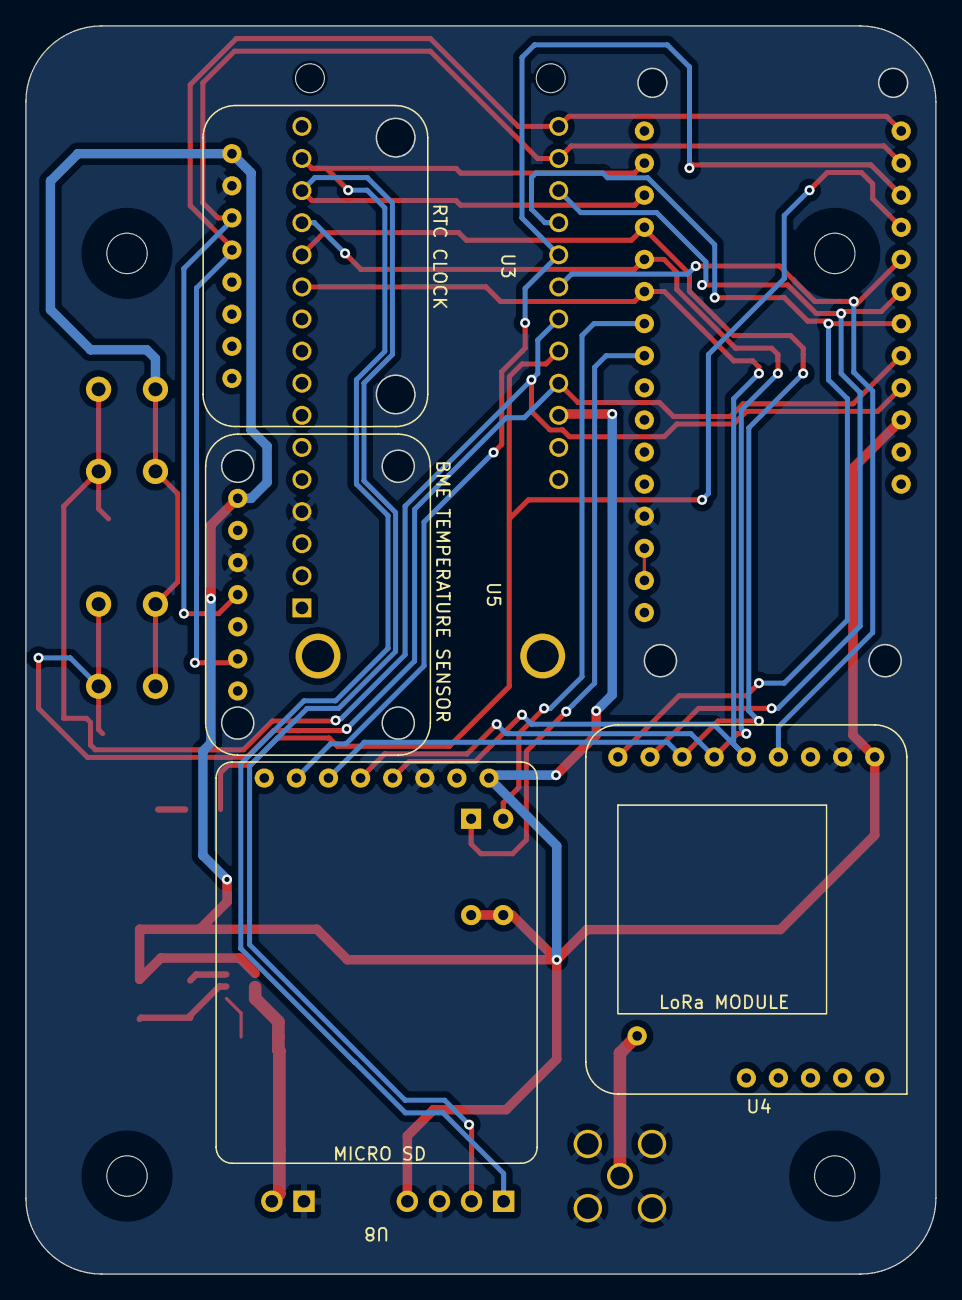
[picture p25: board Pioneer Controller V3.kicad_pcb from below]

Board: 2 copper layers, 72.0 x 98.8 mm, 27 parts (4 on the bottom side), 23 nets.

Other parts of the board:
H1, H2, H3, H4: MountingHole_3.2mm_M3

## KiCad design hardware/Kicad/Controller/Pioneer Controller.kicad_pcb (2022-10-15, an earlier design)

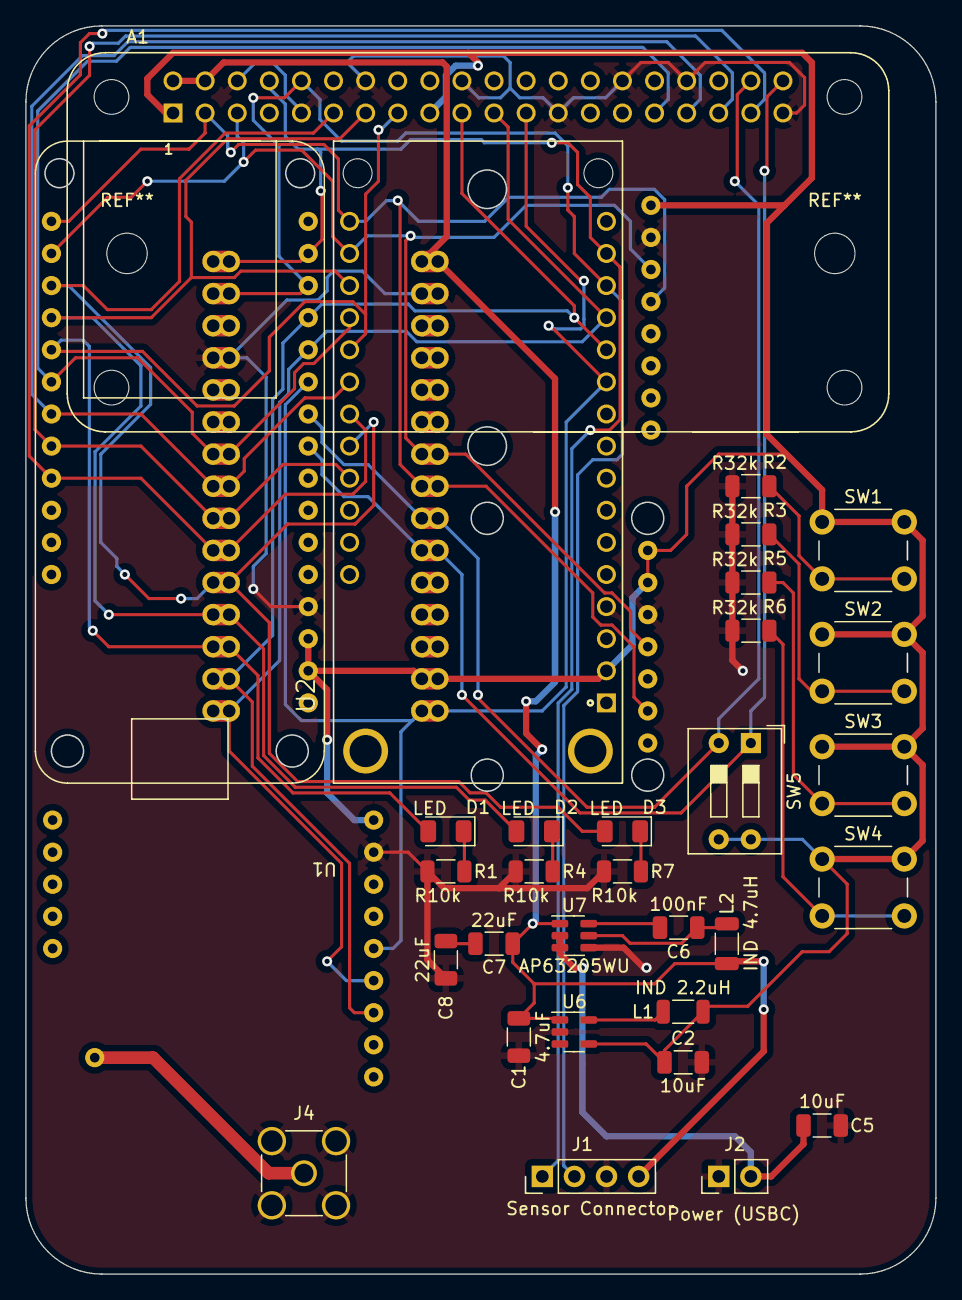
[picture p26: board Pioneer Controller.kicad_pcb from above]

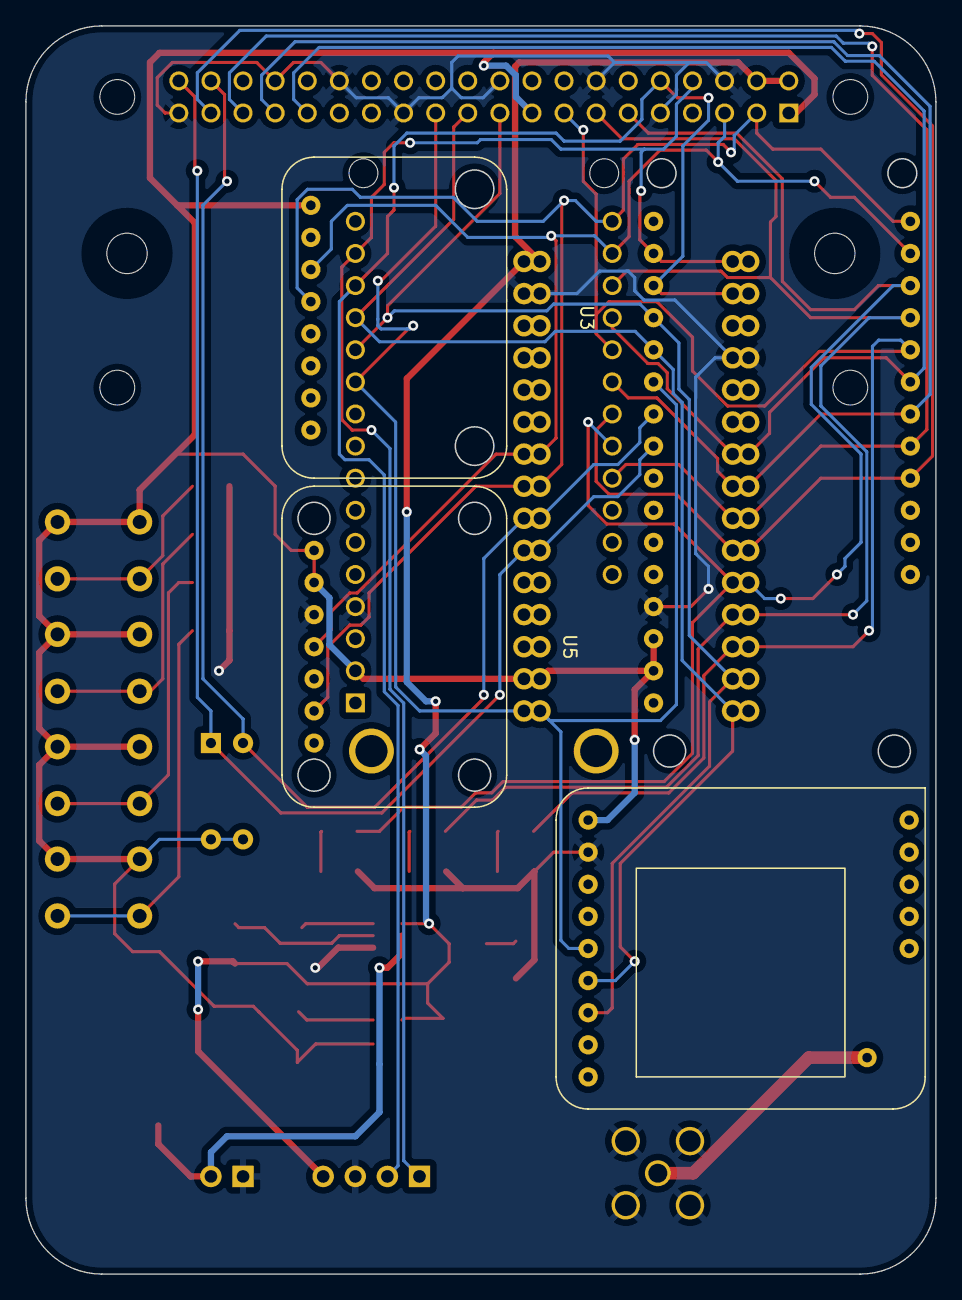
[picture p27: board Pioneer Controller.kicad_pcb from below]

Board: 2 copper layers, 72.0 x 98.8 mm, 35 parts (3 on the bottom side), 32 nets.

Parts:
A1: Pi-Zero; ADA3708_RPI-ZERO
C1: 4.7uF; C_1206_3216Metric
C2, C5: 10uF; C_1206_3216Metric
C6: 100nF; C_1206_3216Metric
C7, C8: 22uF; C_1206_3216Metric
D1, D2, D3: LED; LED_1206_3216Metric
J1: Sensor Connector; PinHeader_1x04_P2.54mm_Vertical
J2: Power (USBC); PinHeader_1x02_P2.54mm_Vertical
J3: Arduino-NANO-33; NANO_33_Socket_Castell
J4: Conn_Coaxial; SMA_Amphenol_132134-11_Vertical
L1: IND 2.2uH; L_1206_3216Metric
L2: IND 4.7uH; L_1206_3216Metric
R1, R4, R7: R10k; R_1206_3216Metric
R2, R3, R5, R6: R32k; R_1206_3216Metric
SW1, SW2, SW3, SW4: SW_MEC_5E; SW_PUSH_6mm
SW5: SW_DIP_x02; SW_DIP_SPSTx02_Slide_9.78x7.26mm_W7.62mm_P2.54mm
U1: ESP32-S3
U2: 2821; XCVR_Adafruit Feather ESP8266
U3: DS3231_Precision_RTC; DS3231 Precision RTC
U4: RFM95W_LoRa_Radio_Transceiver; FM95W LoRa Radio Transceiver
U5: BME280_Temperature_Sensor; BME280 I2C Temperature Sensor
U6: LM3670MF; TSOT-23-5
U7: AP63205WU; TSOT-23-6

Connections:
+3V3: A1.1 (3V3[1]), A1.17 (3V3[2]), C2.1, J3.2, L1.2, SW1.1, SW2.1, SW3.1, SW4.1, SW5.3, SW5.4, U1.3V, U2.2 (3V), U3.VIN, U4.VIN, U5.3P3_V, U5.VIN, U6.4 (FB)
+5V: A1.2 (5V[1]), A1.4 (5V[2]), C1.1, C7.1, J1.4, J3.15, L2.2, U6.1 (Vin), U7.1 (FB)
/LED1: A1.15 (GPIO22/GEN3), D1.2 (A), J3.28, U1.D9, U2.24 (GPIO0)
/LED2: A1.13 (GPIO27/GEN2), D2.2 (A), J3.27, U1.D6, U2.26 (GPIO2)
/LED3: A1.11 (GPIO17/GEN0), D3.2 (A), J3.26, U1.D5, U2.21 (GPIO12)
/MISO: A1.21 (GPIO9/MISO), J3.30, U1.M0, U2.13 (MIS0), U4.MISO
/MOSI: A1.19 (GPIO10/MOSI), J3.29, U1.M1, U2.12 (MOSI), U4.MOSI
/RX: A1.10 (RXD0/GPIO15), J1.2, J3.17, U1.RX, U2.14 (RX)
/SCK: A1.23 (GPIO11/SCLK), J3.1, U1.SCK, U2.11 (SCK), U4.SCK
/SCL: A1.5 (GPIO3/SCL), J3.9, U1.SCL, U2.27 (SCL/GPIO5), U3.SCL, U5.SCK
/SDA: A1.3 (GPIO2/SDA), J3.8, U1.SDA, U2.28 (SDA/GPIO4), U3.SDA, U5.SDI
/SMA: J4.1 (In), U4.SMA
/SW1: A1.37 (GPIO26), J3.25, U1.D13, U2.22 (GPIO13)
/SW2: A1.35 (GPIO19), J3.24, U1.D12, U2.20 (GPIO14)
/SW3: A1.33 (GPIO13), J3.23, U1.D11, U2.23 (GPIO15)
/SW4: A1.31 (GPIO6), J3.22, U1.D10, U2.25 (GPIO16)
/SW5: A1.40 (GPIO21), J3.6, SW5.1, U1.A4
/SW6: A1.38 (GPIO20), J3.7, SW5.2, U1.A5
/TX: A1.8 (TXD0/GPIO14), J1.1, J3.16, U1.TX, U2.15 (TX)
GND: A1.6 (GND[8]), A1.9 (GND[1]), A1.14 (GND[4]), A1.20 (GND[5]), A1.25 (GND[2]), A1.30 (GND[6]), A1.34 (GND[7]), A1.39 (GND[3]), C1.2, C2.2, C5.2, C8.2, J1.3, J2.1, J3.14, J3.19, J4.2 (Ext), R1.2, R2.2, R3.2, R4.2, R5.2, R6.2, R7.2, U1.GND, U2.4 (GND), U3.GND, U4.GND, U5.GND, U6.2 (GND), U7.4 (GND)
unnamed: C6.1, L2.1, U7.5 (SW)
unnamed: C6.2, U7.6 (BST)
unnamed: C7.2, C8.1
unnamed: D1.1 (K), R1.1
unnamed: D2.1 (K), R4.1
unnamed: D3.1 (K), R7.1
unnamed: L1.1, U6.5 (SW)
unnamed: R2.1, SW1.2
unnamed: R3.1, SW2.2
unnamed: R5.1, SW3.2
unnamed: R6.1, SW4.2
VIN: C5.1, J2.2, U7.2 (EN), U7.3 (IN)

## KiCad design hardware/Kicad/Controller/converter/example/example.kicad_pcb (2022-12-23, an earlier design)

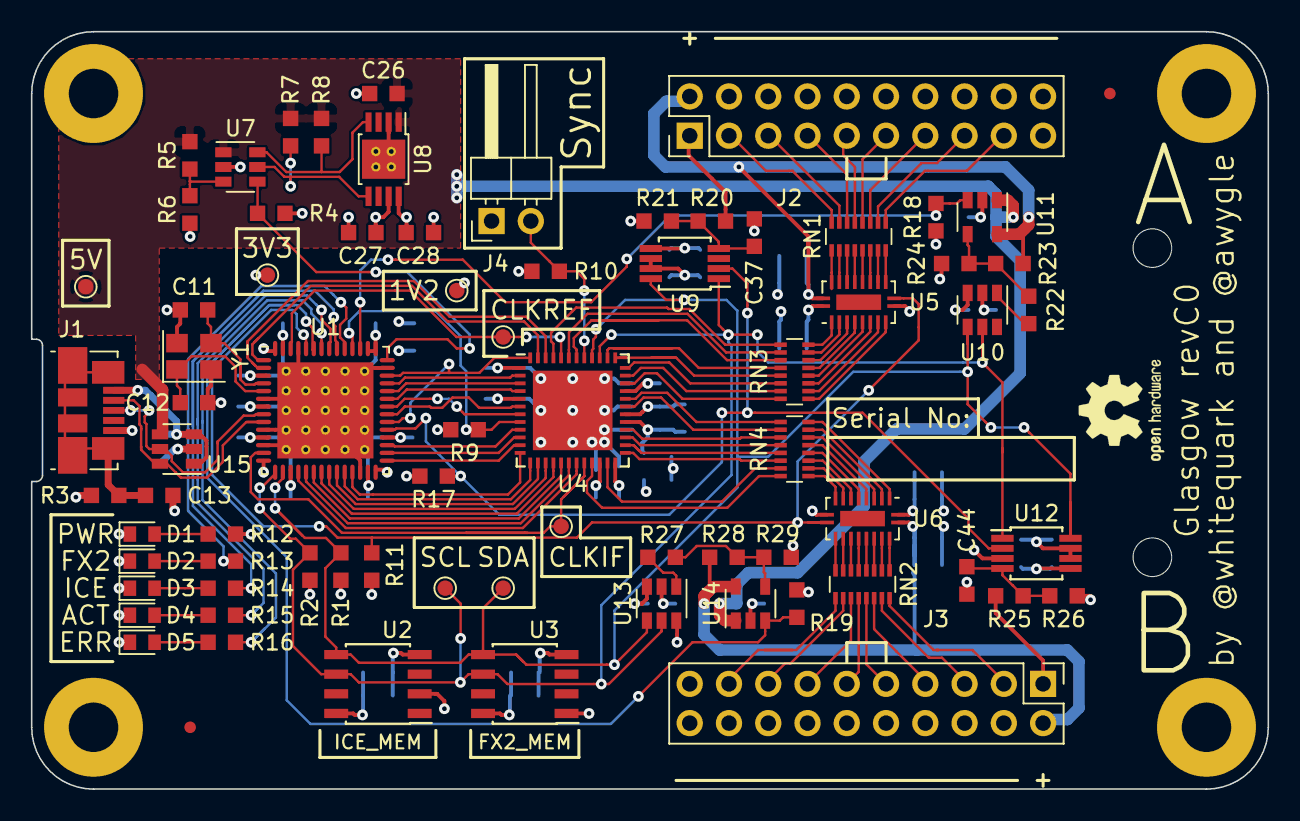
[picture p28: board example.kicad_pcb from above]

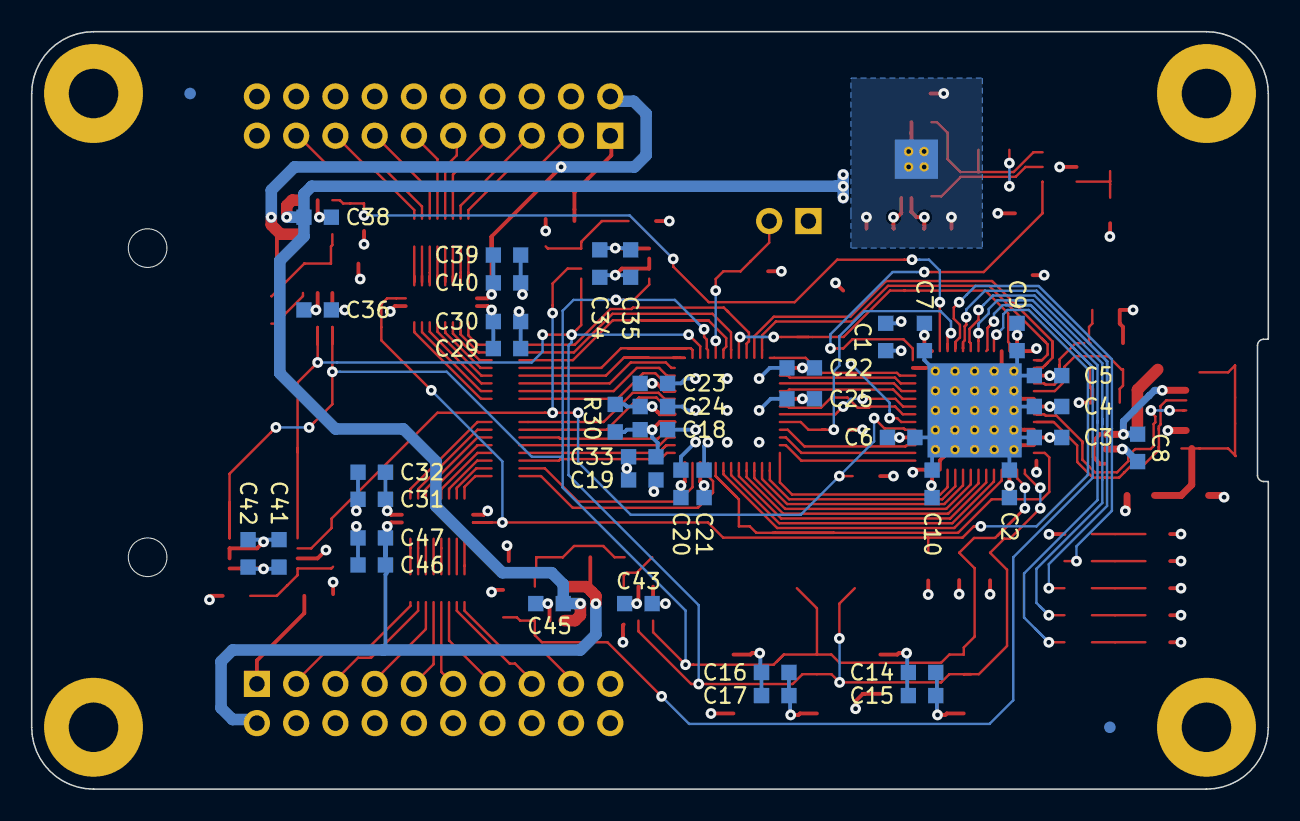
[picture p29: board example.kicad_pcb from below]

Board: 4 copper layers, 80.0 x 49.0 mm, 123 parts (42 on the bottom side), 127 nets.

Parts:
C1, C14, C16, C18, C19, C26, C27, C28, C29, C31, C34, C39, C41, C46: 4u7; C_0603_1608Metric_Pad0.99x1.00mm_HandSolder
C2, C3, C4, C5, C6, C7, C8, C9, C10, C13, C15, C17, C20, C21, C22, C23, C24, C25, C30, C32, C33, C35, C36, C38, C40, C42, C43, C45, C47: u1; C_0603_1608Metric_Pad0.99x1.00mm_HandSolder
C11, C12: 18p; C_0603_1608Metric_Pad0.99x1.00mm_HandSolder
C37, C44: 12n; C_0603_1608Metric_Pad0.99x1.00mm_HandSolder
D1, D2, D3: GRN; LED_0603_1608Metric_Pad0.82x1.00mm_HandSolder
D4: YEL; LED_0603_1608Metric_Pad0.82x1.00mm_HandSolder
D5: RED; LED_0603_1608Metric_Pad0.82x1.00mm_HandSolder
FID1, FID1#2, FID2, FID4: Fiducial_0.75mm_Dia_1.5mm_Outer
J1: USB_B_Micro; USB_Micro-B_Molex_47346-0001
J2, J3: Conn_02x10_Odd_Even; PinHeader_2x10_P2.54mm_Vertical
J4: Conn_01x02; PinHeader_1x02_P2.54mm_Horizontal
MK1, MK2, MK3, MK4: Mounting_Hole_PAD; MountingHole_3.2mm_M3_Pad
MK5, MK6: Mounting_Hole; MountingHole_2.5mm
R1, R2, R12, R13, R14: 2k2; R_0603_1608Metric_Pad0.99x1.00mm_HandSolder
R3: 1M; R_0603_1608Metric_Pad0.99x1.00mm_HandSolder
R4, R6, R7, R8, R9, R11, R17, R18, R19: 100k; R_0603_1608Metric_Pad0.99x1.00mm_HandSolder
R5: 220k; R_0603_1608Metric_Pad0.99x1.00mm_HandSolder
R10, R15: 390; R_0603_1608Metric_Pad0.99x1.00mm_HandSolder
R16: 604; R_0603_1608Metric_Pad0.99x1.00mm_HandSolder
R20, R21, R25, R26: 10k; R_0603_1608Metric_Pad0.99x1.00mm_HandSolder
R22, R27: 49k9; R_0603_1608Metric_Pad0.99x1.00mm_HandSolder
R23, R28: 59k; R_0603_1608Metric_Pad0.99x1.00mm_HandSolder
R24, R29: 24k3; R_0603_1608Metric_Pad0.99x1.00mm_HandSolder
R30: 100; R_0603_1608Metric_Pad0.99x1.00mm_HandSolder
RN1, RN2, RN3, RN4: R_Pack08; R_Array_Convex_8x0602
TP1: 5V; TestPoint_Pad_D1.0mm
TP2: 1V2; TestPoint_Pad_D1.0mm
TP3, TP7: 3V3; TestPoint_Pad_D1.0mm
TP4: SDA; TestPoint_Pad_D1.0mm
TP5: SCL; TestPoint_Pad_D1.0mm
TP6: CLKREF; TestPoint_Pad_D1.0mm
U1: CY7C68013A-56LTX; Cypress_QFN-56-1EP_8x8mm_P0.5mm_EP6.22x6.22mm_ThermalVias
U2: CAT24M01W; SOIC-8_3.9x4.9mm_P1.27mm
U3: CAT24C256W; SOIC-8_3.9x4.9mm_P1.27mm
U4: ICE40UP5K-SG48ITR; QFN-48-1EP_7x7mm_P0.5mm_EP5.15x5.15mm
U5, U6: FXMA108BQX; WQFN-20-1EP_2.5x4.5mm_P0.5mm_EP1x2.9mm
U7: LM3880MF-1AF; SOT-23-6
U8: MIC5355-S4YMME; MSOP-8-1EP_3x3mm_P0.65mm_EP2.54x2.8mm_ThermalVias
U9, U12: ADC081C021CIMM; MSOP-8_3x3mm_P0.65mm
U10, U13: DAC081C081CIMK; SOT-23-6
U11, U14: TPS73101DBV; SOT-23-5
U15: TPD3S014; SOT-23-6
Y1: 24M; Crystal_SMD_3225-4pin_3.2x2.5mm

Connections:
+1V2: C24.1, C25.1, C27.1, R30.2, TP2.1, U4.5, U4.30, U8.7
+3V3: C1.1, C2.1, C3.1, C4.1, C5.1, C6.1, C7.1, C9.1, C10.1, C14.1, C15.1, C16.1, C17.1, C19.1, C20.1, C21.1, C22.1, C23.1, C28.1, C29.1, C30.1, C31.1, C32.1, C34.1, C35.1, C36.1, C41.1, C42.1, C43.1, R1.2, R2.2, R4.2, R10.2, R11.2, R12.1, R17.2, TP3.1, U1.3, U1.7, U1.11, U1.17, U1.27, U1.32, U1.43, U1.44, U1.55, U2.2, U2.8, U3.1, U3.8, U4.1, U4.22, U4.24, U4.33, U5.1, U6.1, U8.8, U9.5, U10.2, U12.5, U13.2
+5V: C26.1, C38.1, C45.1, R5.2, R7.2, R8.2, TP1.1, U7.1, U8.1, U11.1, U14.1, U15.4
/1V2EN: R8.1, U7.6, U8.4
/3V3EN: R7.1, U7.5, U8.5
/A0: U1.37, U4.4
/A1: U1.38, U4.3
/CLKIF: TP7.1, U1.13, U4.20
/CLKREF: TP6.1, U1.54, U4.44
/D0: U1.18, U4.19
/D1: U1.19, U4.18
/D2: U1.20, U4.17
/D3: U1.21, U4.16
/D4: U1.22, U4.15
/D5: U1.23, U4.14
/D6: U1.24, U4.13
/D7: U1.25, U4.12
/ENVA: R18.1, U1.45, U11.3
/ENVB: R19.1, U1.51, U14.3
/FLAGA: U1.29, U4.11
/FLAGB: U1.30, U4.10
/FLAGC: U1.31, U4.9
/FLAGD: U1.34, U1.40, U4.48
/FPGA_DONE: U1.36, U4.7
/IOBufferA/VFB: R22.2, R23.1, R24.2, U11.4
/IOBufferA/VIO: C39.1, C40.1, J2.2, R23.2, U5.20, U11.5
/IOBufferA/VSAMP: C37.1, R20.1, R21.2, U9.4
/IOBufferA/VSENSE: J2.1, R20.2
/IOBufferA/X0: RN3.16, U5.2
/IOBufferA/X1: RN3.15, U5.3
/IOBufferA/X2: RN3.14, U5.4
/IOBufferA/X3: RN3.13, U5.5
/IOBufferA/X4: RN3.12, U5.6
/IOBufferA/X5: RN3.11, U5.7
/IOBufferA/X6: RN3.10, U5.8
/IOBufferA/X7: RN3.9, U5.9
/IOBufferA/Y0: RN1.1, U5.19
/IOBufferA/Y1: RN1.2, U5.18
/IOBufferA/Y2: RN1.3, U5.17
/IOBufferA/Y3: RN1.4, U5.16
/IOBufferA/Y4: RN1.5, U5.15
/IOBufferA/Y5: RN1.6, U5.14
/IOBufferA/Y6: RN1.7, U5.13
/IOBufferA/Y7: RN1.8, U5.12
/IOBufferA/Z0: J2.3, RN1.16
/IOBufferA/Z1: J2.5, RN1.15
/IOBufferA/Z2: J2.7, RN1.14
/IOBufferA/Z3: J2.9, RN1.13
/IOBufferA/Z4: J2.11, RN1.12
/IOBufferA/Z5: J2.13, RN1.11
/IOBufferA/Z6: J2.15, RN1.10
/IOBufferA/Z7: J2.17, RN1.9
/IOBufferB/VFB: R27.2, R28.1, R29.2, U14.4
/IOBufferB/VIO: C46.1, C47.1, J3.2, R28.2, U6.20, U14.5
/IOBufferB/VSAMP: C44.1, R25.1, R26.2, U12.4
/IOBufferB/VSENSE: J3.1, R25.2
/IOBufferB/X0: RN4.16, U6.2
/IOBufferB/X1: RN4.15, U6.3
/IOBufferB/X2: RN4.14, U6.4
/IOBufferB/X3: RN4.13, U6.5
/IOBufferB/X4: RN4.12, U6.6
/IOBufferB/X5: RN4.11, U6.7
/IOBufferB/X6: RN4.10, U6.8
/IOBufferB/X7: RN4.9, U6.9
/IOBufferB/Y0: RN2.1, U6.19
/IOBufferB/Y1: RN2.2, U6.18
/IOBufferB/Y2: RN2.3, U6.17
/IOBufferB/Y3: RN2.4, U6.16
/IOBufferB/Y4: RN2.5, U6.15
/IOBufferB/Y5: RN2.6, U6.14
/IOBufferB/Y6: RN2.7, U6.13
/IOBufferB/Y7: RN2.8, U6.12
/IOBufferB/Z0: J3.3, RN2.16
/IOBufferB/Z1: J3.5, RN2.15
/IOBufferB/Z2: J3.7, RN2.14
/IOBufferB/Z3: J3.9, RN2.13
/IOBufferB/Z4: J3.11, RN2.12
/IOBufferB/Z5: J3.13, RN2.11
/IOBufferB/Z6: J3.15, RN2.10
/IOBufferB/Z7: J3.17, RN2.9
/LED_ACT: R15.1, U1.49
/LED_CY: R13.1, U1.47
/LED_ERR: R16.1, U1.50
/LED_FPGA: R14.1, U1.48
/OE: U1.35, U4.6
/PGOOD: R5.1, R6.2, U7.3
/PKTEND: U1.39, U4.2
/QA0: RN3.1, U4.45
/QA1: RN3.2, U4.43
/QA2: RN3.3, U4.42
/QA3: RN3.4, U4.38
/QA4: RN3.5, U4.37
/QA5: RN3.6, U4.36
/QA6: RN3.7, U4.35
/QA7: RN3.8, U4.34
/QB0: RN4.1, U4.32
/QB1: RN4.2, U4.31
/QB2: RN4.3, U4.28
/QB3: RN4.4, U4.27
/QB4: RN4.5, U4.26
/QB5: RN4.6, U4.25
/QB6: RN4.7, U4.23
/QB7: RN4.8, U4.21
/RD: U1.1, U4.47
/SCL: R2.1, TP5.1, U1.15, U2.6, U3.6, U4.39, U9.1, U10.5, U12.1, U13.5
/SDA: R1.1, TP4.1, U1.16, U2.5, U3.5, U4.40, U9.8, U10.4, U12.8, U13.4
/SHLD: C13.1, J1.6, R3.1
/USB_N: J1.2, U1.9, U15.6
/USB_P: J1.3, U1.8, U15.5
/VCCPLL: C18.1, C33.1, R30.1, U4.29
/VUSB: C8.1, J1.1, U15.1, U15.3
/WR: U1.2, U4.46
/XTALIN: C12.1, U1.5, Y1.1
/XTALOUT: C11.1, U1.4, Y1.3
/~ALERT: R17.1, U1.33, U9.2, U12.2
/~CY_RESET: R4.1, U1.42, U7.4
/~FPGA_RESET: R9.2, U1.46, U4.8
/~OEQ: R11.1, U1.52, U5.11, U6.11
/~SYNC: J4.2, R10.1, U4.41
GND: C1.2, C2.2, C3.2, C4.2, C5.2, C6.2, C7.2, C8.2, C9.2, C10.2, C11.2, C12.2, C13.2, C14.2, C15.2, C16.2, C17.2, C18.2, C19.2, C20.2, C21.2, C22.2, C23.2, C24.2, C25.2, C26.2, C27.2, C28.2, C29.2, C30.2, C31.2, C32.2, C33.2, C34.2, C35.2, C36.2, C37.2, C38.2, C39.2, C40.2, C41.2, C42.2, C43.2, C44.2, C45.2, C46.2, C47.2, D1.1, D2.1, D3.1, D4.1, D5.1, J1.5, J2.4, J2.6, J2.8, J2.10, J2.12, J2.14, J2.16, J2.18, J2.20, J3.4, J3.6, J3.8, J3.10, J3.12, J3.14, J3.16, J3.18, J3.20, J4.1, MK1.1, MK2.1, MK3.1, MK4.1, R3.2, R6.1, R9.1, R18.2, R19.2, R21.1, R24.1, R26.1, R29.1, U1.6, U1.10, U1.12, U1.14, U1.26, U1.28, U1.41, U1.53, U1.56, U1.57, U2.4, U3.4, U4.49, U5.10, U6.10, U7.2, U8.2, U8.9, U9.6, U9.7, U10.3, U11.2, U12.3, U12.6, U12.7, U13.3, U13.6, U14.2, U15.2, Y1.2, Y1.4
unnamed: D1.2, R12.2
unnamed: D2.2, R13.2
unnamed: D3.2, R14.2
unnamed: D4.2, R15.2
unnamed: D5.2, R16.2
unnamed: R22.1, U10.1
unnamed: R27.1, U13.1

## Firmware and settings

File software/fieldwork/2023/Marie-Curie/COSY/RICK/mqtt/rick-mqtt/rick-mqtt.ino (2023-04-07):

/*

Marie Skłodowska-Curie Actions
Project acronym: PIONEER
Grant nr.: 844526
Project Investigator: Federico Dallo (https://github.com/theRosyProject)

Sofware README - last updated infos at: https://github.com/theRosyProject/PIONEER
Software Author: Federico Dallo
Date: April 2023

Step 1)
System creates a WiFi access point at the address 192.168.0.4 for
user configuration:
- get device MAC address
- provide SSID and password of the Local Area Network (Wifi)
- evaluate SSID and password (MQTT Broker Handshake)

On failed handshake:
- reset configuration and get back to Step 1 

On successful handshake:
- automatic system reboot and proceed to Step 2

Step 2)
System creates a HTTP page at the address given by the DHCP:
- evaluate user input for system reset:
  If TRUE get back to Step 1
  If FALSE continue

- Configure MQTT 

- Read from ADC ozone sensors

- Read from ADC CO2 sensor

- Read from two PM2.5 sensors using Software Serial
  Info: https://docs.arduino.cc/tutorials/communication/TwoPortReceive

- Publish over MQTT

Auth: F. Dallo
Date: 18 Mar 2023, Venice, IT

*/

// Libraries for ADC
#include <Wire.h>
#include <Adafruit_ADS1X15.h>
Adafruit_ADS1115 ads1115_OZO;
Adafruit_ADS1115 ads1115_CO2;

// Libraries for handling MQTT
#include "EspMQTTClient.h"
#include <ArduinoJson.h>

// MQTT: ID, server IP, port, username and password
EspMQTTClient client(
  "pioneerNet",
  "cicciopasticcio",
  //"192.168.119.146",  // MQTT Broker server ip M1 Fede su hotspot Motorola
  "192.168.43.42", // MQTT Broker Daniele su Nokia 6
  //"192.168.xxx.xxx",
  "mqttuser",   // Can be omitted if not needed
  "mqttuser",   // Can be omitted if not needed
  "MQTT_RICK_1",     // Client name that uniquely identify your device
  1883              // The MQTT port, default to 1883. this line can be omitted
);

// MQTT: topics
const PROGMEM char* MQTT_SENSOR_TOPIC_DEBUG = "svalbard/debug";
const PROGMEM char* MQTT_SENSOR_TOPIC_PM = "svalbard/pm";
const PROGMEM char* MQTT_SENSOR_TOPIC_PM_1 = "svalbard/pm/pms5003_1";
const PROGMEM char* MQTT_SENSOR_TOPIC_PM_2 = "svalbard/pm/pms5003_2";
const PROGMEM char* MQTT_SENSOR_TOPIC_CO2 = "svalbard/co2";
const PROGMEM char* MQTT_SENSOR_TOPIC_OZONE = "svalbard/ozone";

// Add the library from read from PMS5003 sensors
#include "Adafruit_PM25AQI.h"

// Add the library for using two sensors over software serial port
#include <SoftwareSerial.h>

SoftwareSerial pmSerial1(2, 0);
SoftwareSerial pmSerial2(13, 12);

Adafruit_PM25AQI aqi1 = Adafruit_PM25AQI();
Adafruit_PM25AQI aqi2 = Adafruit_PM25AQI();

void setup() {
  // Open serial for data communication, wait and welcome message
  Serial.begin(115200);
  while (!Serial) {
    delay(10);
  }

  // Initialize ADC
  Serial.println("Init ADC addr48 and addr49");  
  Serial.println("Both in ADC Range: +/- 4.096V  1 bit = 2mV");
  ads1115_OZO.setGain(GAIN_ONE);     // 1x gain   +/- 4.096V  1 bit = 2mV
  ads1115_OZO.begin(0x48); // reading the OZO sensors
  delay(100);
  ads1115_CO2.setGain(GAIN_ONE);
  ads1115_CO2.begin(0x49);
  // ads1115_49.setGain(GAIN_ONE);     // 1x gain   +/- 4.096V  1 bit = 2mV
  // ads1115_49.begin(0x49); // reading the CO2 sensor

  // Initialize serial port for PM
  Serial.println("Serial port open, now opening sensors' serial ports");
  delay(1000);

  // init the MQTT connection
  // Optional functionalities of EspMQTTClient
  client.enableDebuggingMessages(); // Enable debugging messages sent to serial output
  client.enableHTTPWebUpdater(); // Enable the web updater. User and password default to values of MQTTUsername and MQTTPassword. These can be overridded with enableHTTPWebUpdater("user", "password").
  client.enableOTA(); // Enable OTA (Over The Air) updates. Password defaults to MQTTPassword. Port is the default OTA port. Can be overridden with enableOTA("password", port).
  client.enableLastWillMessage("svalbard/debug", "MQTT_RICK_1: I am going offline");  // You can activate the retain flag by setting the third parameter to true

  // Start the sensors serial ports  
  pmSerial2.begin(9600);

  if (! aqi2.begin_UART(&pmSerial2)) { // connect to the sensor over software serial 
    Serial.println("Could not find PM 2.5 sensor 2!");
    while (1) delay(10);
  }

  pmSerial1.begin(9600);

  if (! aqi1.begin_UART(&pmSerial1)) { // connect to the sensor over software serial 
    Serial.println("Could not find PM 2.5 sensor 1!");
    while (1) delay(10);
  }

}

// This function is called once everything is connected (Wifi and MQTT)
// WARNING : YOU MUST IMPLEMENT IT IF YOU USE EspMQTTClient
void onConnectionEstablished()
{
  // Subscribe to "mytopic/test" and display received message to Serial
  //client.subscribe("svalbard/#", [](const String & payload) {
  //  Serial.println(payload);
  //});

  // // Subscribe to "mytopic/wildcardtest/#" and display received message to Serial
  // client.subscribe("mytopic/wildcardtest/#", [](const String & topic, const String & payload) {
  //   Serial.println("(From wildcard) topic: " + topic + ", payload: " + payload);
  // });

  // Publish a message to "debug"
  client.publish(MQTT_SENSOR_TOPIC_DEBUG, "RICK1 connected"); // You can activate the retain flag by setting the third parameter to true

  // // Execute delayed instructions
  // client.executeDelayed(5 * 1000, []() {
  //   client.publish("mytopic/wildcardtest/test123", "This is a message sent 5 seconds later");
  // });
}

void loop() {

  // init loop client MQTT
  client.loop();

  // Reading OZONE sensors 1
  int16_t adc48_0, adc48_1, adc48_2, adc48_3;

  adc48_0 = ads1115_OZO.readADC_SingleEnded(0);
  adc48_1 = ads1115_OZO.readADC_SingleEnded(1);
  adc48_2 = ads1115_OZO.readADC_SingleEnded(2);
  adc48_3 = ads1115_OZO.readADC_SingleEnded(3);
  // formatting the message
  char bufferOZO[50];
  sprintf(bufferOZO, "%02d,%02d,%02d,%02d",
          adc48_0, adc48_1, adc48_2, adc48_3
  );
  Serial.println(bufferOZO);
  // prepare JSON
  StaticJsonDocument<150> rootOZO;
  // DATA START
  rootOZO["WE1"] = (String)adc48_3;
  rootOZO["AUX1"] = (String)adc48_2;
  rootOZO["WE2"] = (String)adc48_1;
  rootOZO["AUX2"]  = (String)adc48_0;
  // DATA END
  char jsonCharOZO[150];
  serializeJson(rootOZO, jsonCharOZO);    
  client.publish(MQTT_SENSOR_TOPIC_OZONE, jsonCharOZO, true);
  yield();
  
  delay(1000);

  // Reading CO2 sensor
  int16_t adc49_0, adc49_1, adc49_2, adc49_3;

  adc49_0 = ads1115_CO2.readADC_SingleEnded(0);
  adc49_1 = ads1115_CO2.readADC_SingleEnded(1);
  adc49_2 = ads1115_CO2.readADC_SingleEnded(2);
  adc49_3 = ads1115_CO2.readADC_SingleEnded(3);
  // formatting the message
  char bufferCO2[50];
  sprintf(bufferCO2, "%02d,%02d,%02d,%02d",
          adc49_0, adc49_1, adc49_2, adc49_3          
  );
  Serial.println(bufferCO2);
  // prepare JSON
  StaticJsonDocument<150> rootCO2;
  // // DATA START
  rootCO2["P"] = (String)adc49_3;
  rootCO2["N"] = (String)adc49_2;
  // DATA END
  char jsonCharCO2[150];
  serializeJson(rootCO2, jsonCharCO2);    
  client.publish(MQTT_SENSOR_TOPIC_CO2, jsonCharCO2, true);
  // yield();
  
  delay(1000);

  
  // Start listen on sensor 1
  pmSerial1.listen();  

  if (pmSerial1.available()) {

    PM25_AQI_Data data1;
   
    if (! aqi1.read(&data1)) {
      Serial.println("Could not read from AQI nr.1");
      delay(500);  // try again in a bit!
      //return;
    }

    // Prepare message for the MQTT
    int PM10std  = data1.pm10_standard;
    int PM25std  = data1.pm25_standard;
    int PM100std = data1.pm100_standard;

    int PM10env  = data1.pm10_env;
    int PM25env  = data1.pm25_env;
    int PM100env = data1.pm100_env;

    int prt03 = data1.particles_03um;
    int prt05 = data1.particles_05um;
    int prt10 = data1.particles_10um;
    int prt25 = data1.particles_25um;
    int prt100= data1.particles_100um;
    // formatting the message
    char bufferPM[100];
    sprintf(bufferPM, "%02d,%02d,%02d,%02d,%02d,%02d,%02d,%02d,%02d,%02d,%02d",
            PM10std, PM25std, PM100std, 
            PM10env, PM25env, PM100env,
            prt03, prt05, prt10, prt25, prt100
    );
    Serial.println(bufferPM);
    // prepare JSON
    StaticJsonDocument<550> root;
    // DATA START
    root["PM10std"] = (String)PM10std;
    root["PM25std"] = (String)PM25std;
    root["PM100std"] = (String)PM100std;
    root["PM10env"]  = (String)PM10env;
    root["PM25env"]  = (String)PM25env;
    root["PM100env"] = (String)PM100env;
    root["prt03"] = (String)prt03;
    root["prt05"] = (String)prt05;
    root["prt10"] = (String)prt10;
    root["prt25"] = (String)prt25;
    root["prt100"]= (String)prt100;
    // DATA END
    char jsonChar[550];
    serializeJson(root, jsonChar);    
    client.publish(MQTT_SENSOR_TOPIC_PM_1, jsonChar, true);
    yield();
    
  }

  delay(1000);

// Start listen on sensor 2
  pmSerial2.listen();

  if (pmSerial2.available()) {

    PM25_AQI_Data data2;

    if (! aqi2.read(&data2)) {
      Serial.println("Could not read from AQI nr.2");
      delay(500);  // try again in a bit!
      //return;
    }

    // Prepare message for the MQTT
    int PM10std  = data2.pm10_standard;
    int PM25std  = data2.pm25_standard;
    int PM100std = data2.pm100_standard;

    int PM10env  = data2.pm10_env;
    int PM25env  = data2.pm25_env;
    int PM100env = data2.pm100_env;

    int prt03 = data2.particles_03um;
    int prt05 = data2.particles_05um;
    int prt10 = data2.particles_10um;
    int prt25 = data2.particles_25um;
    int prt100= data2.particles_100um;
    // formatting the message
    char bufferPM[100];
    sprintf(bufferPM, "%02d,%02d,%02d,%02d,%02d,%02d,%02d,%02d,%02d,%02d,%02d",
            PM10std, PM25std, PM100std, 
            PM10env, PM25env, PM100env,
            prt03, prt05, prt10, prt25, prt100
    );
    Serial.println(bufferPM);
    // prepare JSON
    StaticJsonDocument<550> root;
    // DATA START
    root["PM10std"] = (String)PM10std;
    root["PM25std"] = (String)PM25std;
    root["PM100std"] = (String)PM100std;
    root["PM10env"]  = (String)PM10env;
    root["PM25env"]  = (String)PM25env;
    root["PM100env"] = (String)PM100env;
    root["prt03"] = (String)prt03;
    root["prt05"] = (String)prt05;
    root["prt10"] = (String)prt10;
    root["prt25"] = (String)prt25;
    root["prt100"]= (String)prt100;
    // DATA END
    char jsonChar[550];
    serializeJson(root, jsonChar);    
    client.publish(MQTT_SENSOR_TOPIC_PM_2, jsonChar, true);
    yield();

    

  }

  delay(1000);

}

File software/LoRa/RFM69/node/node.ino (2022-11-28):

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
// Licence can be viewed at                               
// http://www.gnu.org/licenses/gpl-3.0.txt
//
// Please maintain this license information along with authorship
// and copyright notices in any redistribution of this code
// **********************************************************************************
#include <RFM69.h>         //get it here: https://www.github.com/lowpowerlab/rfm69
#include <RFM69_ATC.h>     //get it here: https://www.github.com/lowpowerlab/rfm69
#include <SPIFlash.h>      //get it here: https://www.github.com/lowpowerlab/spiflash

//*********************************************************************************************
//************ IMPORTANT SETTINGS - YOU MUST CHANGE/CONFIGURE TO FIT YOUR HARDWARE ************
//*********************************************************************************************
// Address IDs are 10bit, meaning usable ID range is 1..1023
// Address 0 is special (broadcast), messages to address 0 are received by all *listening* nodes (ie. active RX mode)
// Gateway ID should be kept at ID=1 for simplicity, although this is not a hard constraint
//*********************************************************************************************
#define NODEID        2    // keep UNIQUE for each node on same network
#define NETWORKID     100  // keep IDENTICAL on all nodes that talk to each other
#define GATEWAYID     1    // "central" node

//*********************************************************************************************
// Frequency should be set to match the radio module hardware tuned frequency,
// otherwise if say a "433mhz" module is set to work at 915, it will work but very badly.
// Moteinos and RF modules from LowPowerLab are marked with a colored dot to help identify their tuned frequency band,
// see this link for details: https://lowpowerlab.com/guide/moteino/transceivers/
// The below examples are predefined "center" frequencies for the radio's tuned "ISM frequency band".
// You can always set the frequency anywhere in the "frequency band", ex. the 915mhz ISM band is 902..928mhz.
//*********************************************************************************************
//#define FREQUENCY   RF69_433MHZ
#define FREQUENCY   RF69_868MHZ
//#define FREQUENCY     RF69_915MHZ
//#define FREQUENCY_EXACT 916000000 // you may define an exact frequency/channel in Hz
#define ENCRYPTKEY    "sampleEncryptKey" //exactly the same 16 characters/bytes on all nodes!
#define IS_RFM69HW_HCW  //uncomment only for RFM69HW/HCW! Leave out if you have RFM69W/CW!
//*********************************************************************************************
//Auto Transmission Control - dials down transmit power to save battery
//Usually you do not need to always transmit at max output power
//By reducing TX power even a little you save a significant amount of battery power
//This setting enables this gateway to work with remote nodes that have ATC enabled to
//dial their power down to only the required level (ATC_RSSI)
#define ENABLE_ATC    //comment out this line to disable AUTO TRANSMISSION CONTROL
#define ATC_RSSI      -80
//*********************************************************************************************
#define SERIAL_BAUD   115200

int TRANSMITPERIOD = 200; //transmit a packet to gateway so often (in ms)
char payload[] = "123 ABCDEFGHIJKLMNOPQRSTUVWXYZ";
char buff[20];
byte sendSize=0;
boolean requestACK = false;
//SPIFlash flash(SS_FLASHMEM, 0xEF30); //EF30 for 4mbit  Windbond chip (W25X40CL)
SPIFlash flash(15);

#ifdef ENABLE_ATC
  RFM69_ATC radio;
#else
  RFM69 radio;
#endif

void setup() {
  Serial.begin(SERIAL_BAUD);
  radio.initialize(FREQUENCY,NODEID,NETWORKID);
  Serial.print("Tioca'");
#ifdef IS_RFM69HW_HCW
  radio.setHighPower(); //must include this only for RFM69HW/HCW!
#endif

#ifdef ENCRYPTKEY
  radio.encrypt(ENCRYPTKEY);
#endif

#ifdef FREQUENCY_EXACT
  radio.setFrequency(FREQUENCY_EXACT); //set frequency to some custom frequency
#endif
  
//Auto Transmission Control - dials down transmit power to save battery (-100 is the noise floor, -90 is still pretty good)
//For indoor nodes that are pretty static and at pretty stable temperatures (like a MotionMote) -90dBm is quite safe
//For more variable nodes that can expect to move or experience larger temp drifts a lower margin like -70 to -80 would probably be better
//Always test your ATC mote in the edge cases in your own environment to ensure ATC will perform as you expect
#ifdef ENABLE_ATC
  radio.enableAutoPower(ATC_RSSI);
#endif

  char buff[50];
  sprintf(buff, "\nTransmitting at %d Mhz...", FREQUENCY==RF69_433MHZ ? 433 : FREQUENCY==RF69_868MHZ ? 868 : 915);
  Serial.println(buff);

  if (flash.initialize())
  {
    Serial.print("SPI Flash Init OK ... UniqueID (MAC): ");
    flash.readUniqueId();
    for (byte i=0;i<8;i++)
    {
      Serial.print(flash.UNIQUEID[i], HEX);
      Serial.print(' ');
    }
    Serial.println();
  }
  else
    Serial.println("SPI Flash MEM not found (is chip soldered?)...");

#ifdef ENABLE_ATC
  Serial.println("RFM69_ATC Enabled (Auto Transmission Control)\n");
#endif
}

void Blink(byte PIN, int DELAY_MS)
{
  pinMode(PIN, OUTPUT);
  digitalWrite(PIN,HIGH);
  delay(DELAY_MS);
  digitalWrite(PIN,LOW);
}
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

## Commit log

2022-09-19 fix: adding documentation for ESP32
2022-09-26 finished schematic
    [Pioneer Controller.kicad_pcb, Pioneer Controller.kicad_sch]
2022-09-27 fix: adding infos on antenna. adding log of meeting
    [Naichen_workinghrs.csv]
2022-09-27 fix: adding the connector for the PCB
2022-10-02 did some 3D model stuff
    [Box_Assembly.SLDASM, Box_Bottom.SLDPRT, Box_Lid.SLDPRT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]
2022-10-02 finished first PCB draft
    [2821 Adafruit ESP8266 Feather.step, Pioneer Controller.kicad_pcb, Pioneer Controller.kicad_sch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]
2022-10-04 feat: adding link to power and data connector
2022-10-08 PCB 3D model
    [PCB_Model.step]
2022-10-08 some more 3D model changes
    [10-Pin Header - Female - 2.54mm.step, 11-Pin Header - Female - 2.54mm.step, 12-Pin Header - Female - 2.54mm.step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]
2022-10-10 more 3D modelling stuff
    [Board.SLDPRT, Box_Assembly.SLDASM, PCB_Assembly.SLDASM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]
2022-10-10 more PCb updates
    [Pioneer Controller.kicad_pcb, Pioneer Controller.step]
2022-10-10 more 3D model updates
    [2821 Adafruit ESP8266 Feather.step, 2x20 Stacking Header.step, 5300 ESP32-S2 TFT Feather.SLDASM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]
2022-10-13 updated 3.3V PMIC
    [Pioneer Controller.kicad_pcb, Pioneer Controller.kicad_sch]
2022-10-15 updated 3D model
    [Adafruit ESP8266 Feather.SLDPRT]
2022-10-25 fix: orders submitted
    [78418501.csv]
2022-11-17 feat: reordering the filesystem considering the project structure reported here: https://drivendata.github.io/cookiecutter-data-science/
    [78418501.csv]
2022-11-22 soft and pins connections between ESP8266 and LoRa
    [ConfigurationVariables.h]
2022-11-28 did more stuff for sensor box
    [10-Pin Header - Female - 2.54mm.step, 11-Pin Header - Female - 2.54mm.step, 12-Pin Header - Female - 2.54mm.step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]
2022-12-07 fix: now sending packet only if serial message is complete
    [LoRa_TX.ino]
2022-12-23 stuff 2
    [Pioneer Controller-B_Cu.gbr, Pioneer Controller-B_Mask.gbr, Pioneer Controller-B_Paste.gbr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]
2022-12-28 started main controller V2
    [Pioneer Controller V2.kicad_pcb, Pioneer Controller V2.kicad_sch, Sensor.kicad_pcb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]
2023-01-05 finished sensor PCB
    [Sensor.kicad_pcb, Sensor.kicad_sch]
2023-01-13 small pcb changes
2023-01-13 added PCB model
    [Sebsor_PCB.SLDPRT]
2023-01-14 updated PCBS
    [Pioneer Controller V2.kicad_pcb, Pioneer Controller V2.kicad_sch, Sensor.kicad_pcb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]
2023-01-14 updated PCB labels
    [Sensor.kicad_pcb]
2023-01-17 added extra resistor
    [Sensor.kicad_pcb, Sensor.kicad_sch]
2023-03-03 updated 3D models
    [NDIR Transmitter.SLDPRT, PCB_Holder.SLDPRT, PCB_Holder.STL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]
2023-03-28 feat: suggestions for finalize the PCBs
2023-03-31 updated footptint
    [PCB v1.f3d, PCB v1.iges, PCB_Model.step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]
2023-04-11 fixed CS to gpio16
    [SensorV2.kicad_pcb, SensorV2.kicad_sch]
2023-04-18 updated PCB
    [Pioneer Controller V3.kicad_pcb, Pioneer Controller V3.kicad_sch]
2023-04-19 updated 5v
    [Pioneer Controller V3.kicad_pcb, Pioneer Controller V3.kicad_sch]
2023-04-20 feat: adding qr code for the project and manual for the pinout of esp32
2023-04-22 added some changes
    [Pioneer Controller V3.kicad_pcb, SensorV2.kicad_pcb, SensorV2.kicad_sch]
2023-04-24 feat: last kicad updates before sending order
    [Pioneer Controller V3-B_Cu.gbr, Pioneer Controller V3-B_Mask.gbr, Pioneer Controller V3-B_Paste.gbr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]

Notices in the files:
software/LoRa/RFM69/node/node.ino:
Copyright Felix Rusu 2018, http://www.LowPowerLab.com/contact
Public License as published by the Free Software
